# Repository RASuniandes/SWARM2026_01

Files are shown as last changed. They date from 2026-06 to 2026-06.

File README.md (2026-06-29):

# SWARM - Sistema de Control para Robot Móvil

## Descripción General

Este repositorio contiene el sistema completo de control para un robot móvil de 4 ruedas omnidireccionales, desarrollado en la Universidad de los Andes. El proyecto integra:

- **Hardware**: ESP32 con 4 motores DC con encoders y drivers L8871
- **Software**: ROS 2 (Robot Operating System) con múltiples modos de control
- **Sensores**: LiDAR YDLidar para navegación autónoma
- **Visión**: MediaPipe para seguimiento de personas

## Estructura del Proyecto

```
SWARM/
├── ros4meetup/              # Paquete principal ROS2
│   ├── ros4meetup/          # Workspace de ROS2
│   │   ├── src/             # Código fuente
│   │   │   ├── ros4meetup/  # Nodos de control
│   │   │   ├── lidar/       # Driver del LiDAR
│   │   │   └── ...          # Otros paquetes
│   │   └── ...              # Build, install, log
│   └── README.md            # Documentación detallada de ROS2
├── CódigoControl/           # Firmware para ESP32 (Arduino)
├── Control SWARM/           # Diseños de PCB (KiCad)
├── Electrónica/             # Esquemáticos y documentación electrónica
├── Dashboard preliminar/    # Interfaz web de monitoreo
└── ojos_frontales/          # Codigo ESP32 para ojos (Matriz 64x2)
```

## Características Principales

### Modos de Control

1. **Vision** (por defecto): Seguimiento de personas usando MediaPipe
2. **Autonomous**: Navegación autónoma con evitación de obstáculos (LiDAR)
3. **Teleop**: Control manual por teclado (W/A/S/D)
4. **Remote**: Control remoto desde ESP32
5. **Web**: Control desde interfaz web

### Arquitectura

```
[Controladores]  →  [Router]  →  [Serial Bridge]  →  [ESP32]  →  [Motores]
                      ↓ cmd_vel
                  [Comandos de velocidad]
```

Cada controlador publica en su propio topic (`vision_command`, `autonomous_command`, etc.). El **Router** selecciona qué controlador está activo y reenvía sus comandos a `cmd_vel`. El **Serial Bridge** convierte estos comandos a JSON y los envía al ESP32 por puerto serial.

## Inicio Rápido

### Requisitos

- Ubuntu 22.04 o superior
- ROS 2 Humble
- Python 3.10+
- Arduino IDE (para firmware ESP32)

### Instalación

1. **Clonar el repositorio:**
```bash
git clone https://github.com/RASuniandes/SWARM.git
cd SWARM/ros4meetup
```

2. **Configurar el entorno ROS2:**
```bash
source ros4meetup/ros.bash
```

3. **Compilar el workspace:**
```bash
cd ros4meetup
colcon build
source install/setup.bash
```

4. **Cargar firmware en ESP32:**
   - Ver documentación en `ros4meetup/firmware/README.md`

### Ejecución

1. **Iniciar el sistema básico:**
```bash
# Terminal 1: Router
ros2 run ros4meetup router

# Terminal 2: Serial Bridge
ros2 run ros4meetup serial_bridge

# Terminal 3: Controlador (elige uno)
ros2 run ros4meetup vision_controller
# o
ros2 run ros4meetup autonomous_controller
# o
ros2 run ros4meetup teleop_controller
```

2. **Cambiar de modo:**
```bash
ros2 topic pub /config std_msgs/String "data: 'autonomous'" --once
```

## Documentación Adicional

- **ROS2 y Nodos**: Ver `ros4meetup/README.md`
- **Firmware ESP32**: Ver `ros4meetup/firmware/README.md`
- **Electrónica**: Ver `Electrónica/`
- **PCB**: Ver `Control SWARM/`

## Desarrollo

### Estructura de Topics ROS2

- `/cmd_vel` (Twist): Comandos de velocidad final al robot
- `/config` (String): Cambio de modo de control
- `/vision_command` (Twist): Comandos del controlador de visión
- `/autonomous_command` (Twist): Comandos del controlador autónomo
- `/teleop_command` (Twist): Comandos del control por teclado
- `/remote_command` (Twist): Comandos remotos desde ESP32
- `/laser_scan` (LaserScan): Datos del LiDAR
- `/esp_feedback` (String): Retroalimentación del ESP32
- `/faces_direction` (String): Dirección para LEDs faciales

### Hardware

- **Microcontrolador**: ESP32
- **Motores**: 4x DC con reductora 1:80 y encoders (12 PPR)
- **Drivers**: L8871 (H-bridge)
- **Sensor**: YDLidar X4
- **Cámara**: USB o CSI para visión

## Licencia

MIT

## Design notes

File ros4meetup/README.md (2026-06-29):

# ros4meetup - Paquete ROS2 para Control de Robot SWARM

## Índice

1. [Descripción General](#descripción-general)
2. [Arquitectura del Sistema](#arquitectura-del-sistema)
3. [Nodos y Funcionalidad](#nodos-y-funcionalidad)
4. [Instalación](#instalación)
5. [Uso](#uso)
6. [Topics y Mensajes](#topics-y-mensajes)
7. [Dependencias](#dependencias)
8. [Solución de Problemas](#solución-de-problemas)

---

## Descripción General

`ros4meetup` es un paquete ROS2 Humble que implementa un sistema de control multi-modal para un robot móvil con 4 ruedas omnidireccionales. El sistema permite cambiar entre diferentes estrategias de control de manera dinámica:

- 👁️ **Visión por computadora**: Seguimiento de personas con MediaPipe
- 🤖 **Navegación autónoma**: Evitación de obstáculos con LiDAR
- 🎮 **Control manual**: Teclado (WASD)
- 📱 **Control remoto**: Desde ESP32 o aplicación móvil
- 🌐 **Interfaz web**: Dashboard de monitoreo y control

### Características

- **Arquitectura modular**: Cada modo de control es un nodo independiente
- **Cambio de modo en caliente**: Sin necesidad de reiniciar el sistema
- **Comunicación serial robusta**: Bridge bidireccional con ESP32
- **Integración con sensores**: LiDAR YDLidar X4 y cámara USB/CSI

---

## Arquitectura del Sistema

```
┌───────────────────────────────────────────────┐
│              CONTROLADORES ROS2               │
│  ┌────────────────────────────────────────┐   │
│  │  vision_controller                     │   │
│  │  autonomous_controller                 │   │
│  │  teleop_controller                     │   │
│  │  (web_controller)                      │   │
│  └─────────────────┬──────────────────────┘   │
│                    │                          │
│                    │ *_command topics         │
│                    │                          │
│                    ↓                          │
│           ┌───────────────────┐               │
│           │   ROUTER          │               │
│           │  (Selector de     │               │
│           │   modo activo)    │               │
│           └────────┬─────────-┘               │
│                    │                          │
│                    │ /cmd_vel                 │
│                    ↓                          │
│           ┌───────────────────┐               │
│           │  SERIAL BRIDGE    │               │
│           │  (ROS ↔ JSON)     │               │
│           └────────┬──────────┘               │
└────────────────────│──────────────────────────┘
                     │ Serial USB (/dev/ttyUSB0)
                     ↓
            ┌────────────────────┐
            │      ESP32         │
            │  (Control de       │
            │   motores)         │
            └────────┬───────────┘
                     │
                     ↓
          ┌────────────────────────┐
          │  4 Motores + Encoders  │
          └────────────────────────┘
```

### Flujo de Datos

1. **Generación de Comandos**: Los controladores leen sensores (cámara, LiDAR, teclado) y publican comandos `Twist` en sus topics específicos
2. **Selección**: El Router suscribe al topic del modo activo y reenvía a `/cmd_vel`
3. **Serialización**: Serial Bridge convierte `Twist` a JSON: `{"linear_speed": X, "angular_speed": Z}`
4. **Transmisión**: Envía el JSON por serial a ESP32
5. **Control de Hardware**: ESP32 calcula PWM para cada motor y cierra el lazo con encoders

---

## Nodos y Funcionalidad

### 1. `router` - Enrutador de Modos

**Archivo**: `src/ros4meetup/router.py`

**Función**: Selecciona dinámicamente qué controlador tiene prioridad.

**Topics**:
- **Suscribe**: `/config` (String) - Cambio de modo
- **Suscribe**: `/{mode}_command` (Twist) - Comandos del modo activo
- **Publica**: `/cmd_vel` (Twist) - Comandos seleccionados

**Modos válidos**: `remote`, `autonomous`, `vision`, `web`, `teleop`

**Ejemplo de uso**:
```bash
# Cambiar a modo autónomo
ros2 topic pub /config std_msgs/String "data: 'autonomous'" --once
```

---

### 2. `serial_bridge` - Puente Serial

**Archivo**: `src/ros4meetup/serial_bridge.py`

**Función**: Traduce mensajes ROS2 ↔ JSON para comunicación con ESP32.

**Características**:
- **Comunicación bidireccional**: Lee y escribe en puerto serial
- **Thread separado** para lectura no bloqueante
- **Puerto**: `/dev/ttyUSB0` a 115200 baudios

**Topics**:
- **Suscribe**: `/cmd_vel` (Twist)
- **Publica**: `/esp_feedback` (String) - Mensajes del ESP32
- **Publica**: `/remote_command` (Twist) - Control remoto desde ESP32

**Formato JSON enviado al ESP32**:
```json
{
  "linear_speed": 100,
  "angular_speed": 50
}
```

**Formato JSON recibido del ESP32**:
```json
{
  "mode": "autonomous",
  "feedback": "Battery: 12.5V",
  "remote_control": {"x": 50, "z": -20}
}
```

---

### 3. `vision_controller` - Seguimiento de Personas

**Archivo**: `src/ros4meetup/vision_controller.py`

**Función**: Sigue a una persona usando detección de pose con MediaPipe.

**Algoritmo**:
1. **Detección**: Identifica hombros o caderas de la persona más cercana
2. **Centrado lateral**: Calcula velocidad angular para centrar la persona
3. **Distancia**: Estima profundidad por tamaño (ratio de ancho de hombros)
4. **Control**:
   - Si está muy cerca (ratio > 0.4): retrocede
   - Si está bien (0.25-0.4): se detiene
   - Si está lejos (< 0.25): avanza

**Topics**:
- **Publica**: `/vision_command` (Twist)

**Parámetros**:
- Velocidad máxima: 100 (normalizada)
- FPS: 10 Hz

---

### 4. `autonomous_controller` - Navegación Autónoma

**Archivo**: `src/ros4meetup/autonomous_controller.py`

**Función**: Navega evitando obstáculos usando datos del LiDAR.

**Algoritmo**:
1. **Lectura**: Procesa datos del LiDAR en 3 zonas (frente, izquierda, derecha)
2. **Detección de obstáculos**: Si la distancia frontal < 0.5m
3. **Decisión**: Gira hacia el lado con más espacio
4. **Ejecución**: Avanza o gira según la situación

**Topics**:
- **Suscribe**: `/laser_scan` (LaserScan)
- **Publica**: `/autonomous_command` (Twist)

**Parámetros**:
- Velocidad lineal: 70
- Velocidad angular: 70
- Distancia mínima: 0.5 metros

---

### 5. `teleop_controller` - Control Manual

**Archivo**: `src/ros4meetup/teleop_controller.py`

**Función**: Control por teclado en tiempo real.

**Teclas**:
- `W`: Avanzar
- `S`: Retroceder
- `A`: Girar izquierda
- `D`: Girar derecha
- `SPACE`: Detener
- `Q`: Salir

**Topics**:
- **Publica**: `/teleop_command` (Twist)

---

### 6. `ojosnodo` - Control de LEDs Faciales

**Archivo**: `src/ros4meetup/ojosnodo.py`

**Función**: Detecta la dirección de movimiento y publica comandos para LEDs "faciales" del robot.

**Lógica**:
- Analiza `/cmd_vel` y determina dirección: `front`, `back`, `left`, `right`, `none`
- Publica en `/faces_direction` para que el ESP32 encienda los LEDs correspondientes

**Topics**:
- **Suscribe**: `/cmd_vel` (Twist)
- **Publica**: `/faces_direction` (String)

---

## Instalación

### Prerrequisitos

```bash
# ROS2 Humble (Ubuntu 22.04)
sudo apt update
sudo apt install ros-humble-desktop python3-colcon-common-extensions

# Dependencias Python
sudo apt install python3-pip
pip3 install pyserial mediapipe opencv-python

# Driver del LiDAR YDLidar
sudo apt install ros-humble-ydlidar-ros2-driver
```

### Compilación

```bash
cd ~/Documents/Ivan/Uniandes/SWARM/ros4meetup/ros4meetup

# Compilar todos los paquetes
colcon build

# Compilar solo ros4meetup
colcon build --packages-select ros4meetup

# Source del workspace
source install/setup.bash
# o, hacer ros.bash, asegurando que sea ejectuable
chmod -x ./ros.bah
./ros.bash
```

### Configuración del Puerto Serial

```bash
# Dar permisos al usuario para acceder a puertos seriales
sudo usermod -aG dialout $USER
# Cerrar sesión y volver a entrar

# Verificar que el ESP32 esté conectado
ls /dev/ttyUSB*
# Debería mostrar: /dev/ttyUSB0 (o similar)

# Si es necesario, modificar el puerto en serial_bridge.py línea 22
```

---

## Uso

### Inicio Completo del Sistema

**Opción 1: Terminales Separadas**

```bash
# Terminal 1: Router
source ~/SWARM/ros4meetup/ros4meetup/install/setup.bash
ros2 run ros4meetup router

# Terminal 2: Serial Bridge
source ~/SWARM/ros4meetup/ros4meetup/install/setup.bash
ros2 run ros4meetup serial_bridge

# Terminal 3: Controlador de Visión (modo por defecto)
source ~/SWARM/ros4meetup/ros4meetup/install/setup.bash
ros2 run ros4meetup vision_controller

# Terminal 4 (opcional): Nodo de LEDs faciales
source ~/SWARM/ros4meetup/ros4meetup/install/setup.bash
ros2 run ros4meetup ojosnodo
```

**Opción 2: Usando tmux o screen**

```bash
# Crear script de inicio
cat > ~/start_swarm.sh << 'EOF'
#!/bin/bash
source ~/SWARM/ros4meetup/ros4meetup/install/setup.bash

tmux new-session -d -s swarm
tmux send-keys -t swarm 'ros2 run ros4meetup router' C-m
tmux split-window -t swarm
tmux send-keys -t swarm 'ros2 run ros4meetup serial_bridge' C-m
tmux split-window -t swarm
tmux send-keys -t swarm 'ros2 run ros4meetup vision_controller' C-m
tmux attach -t swarm
EOF

chmod +x ~/start_swarm.sh
./start_swarm.sh
```

### Cambio de Modo de Control

```bash
# Cambiar a modo autónomo (requiere LiDAR)
ros2 topic pub /config std_msgs/String "data: 'autonomous'" --once
ros2 run ros4meetup autonomous_controller

# Cambiar a control por teclado
ros2 topic pub /config std_msgs/String "data: 'teleop'" --once
ros2 run ros4meetup teleop_controller

# Volver a modo de visión
ros2 topic pub /config std_msgs/String "data: 'vision'" --once
```

### Monitoreo

```bash
# Ver lista de nodos activos
ros2 node list

# Ver topics activos
ros2 topic list

# Monitorear comandos de velocidad
ros2 topic echo /cmd_vel

# Ver información del LiDAR
ros2 topic echo /laser_scan

# Ver feedback del ESP32
ros2 topic echo /esp_feedback

# Visualizar en RViz
ros2 run rviz2 rviz2
# Agregar: LaserScan (/laser_scan), TF, etc.
```

---

## Topics y Mensajes

### Topics Principales

| Topic | Tipo | Dirección | Descripción |
|---|---|---|---|
| `/cmd_vel` | Twist | ROS → ESP | Comandos de velocidad finales |
| `/config` | String | Usuario | Selección de modo de control |
| `/vision_command` | Twist | Nodo | Comandos del controlador de visión |
| `/autonomous_command`| Twist | Nodo | Comandos del controlador autónomo |
| `/teleop_command` | Twist | Nodo | Comandos del control por teclado |
| `/remote_command` | Twist | ESP → ROS | Comandos remotos desde ESP32 |
| `/laser_scan` | LaserScan | LiDAR | Datos del sensor LiDAR |
| `/esp_feedback` | String | ESP → ROS | Retroalimentación del microcontrolador |
| `/faces_direction` | String | ROS → ESP | Dirección para LEDs faciales |

### Estructura del Mensaje Twist

```python
geometry_msgs/Twist:
  linear:
    x: float  # Velocidad lineal (0-100 para este robot)
    y: 0.0    # No usado (robot no holonómico)
    z: 0.0    # No usado
  angular:
    x: 0.0    # No usado
    y: 0.0    # No usado
    z: float  # Velocidad angular (0-100 para este robot)
```

---

## Dependencias

### Paquetes ROS2

```xml
<depend>rclpy</depend>
<depend>std_msgs</depend>
<depend>geometry_msgs</depend>
<depend>sensor_msgs</depend>
<depend>std_srvs</depend>
```

### Bibliotecas Python

```bash
pip3 install pyserial      # Comunicación serial
pip3 install mediapipe     # Detección de pose
pip3 install opencv-python # Procesamiento de imagen
```

### Hardware

- **ESP32**: Microcontrolador principal
- **4 Motores DC**: Con reductora 1:80 y encoders de 12 PPR
- **Drivers L8871**: H-bridge para control de motores
- **YDLidar X4**: Sensor LiDAR de 360°
- **Cámara USB o CSI**: Para visión por computadora

---

## Solución de Problemas

### Error: "Could not open serial port"

```bash
# Verificar permisos
ls -l /dev/ttyUSB0
sudo chmod 666 /dev/ttyUSB0

# Agregar usuario al grupo dialout
sudo usermod -aG dialout $USER
# Cerrar sesión y volver a entrar
```

### Error: "Could not open camera"

```bash
# Verificar dispositivos de cámara
ls /dev/video*

# Probar cámara con OpenCV
python3 -c "import cv2; cap = cv2.VideoCapture(0); print(cap.isOpened())"

# Si no funciona, cambiar índice en vision_controller.py línea 16
# cv2.VideoCapture(1)  # o 2, 3, etc.
```

### Error: "Config service not available"

```bash
# Verificar que el router esté corriendo
ros2 node list | grep router

# Reiniciar el router
ros2 run ros4meetup router
```

### El robot no se mueve

```bash
# 1. Verificar que el ESP32 esté recibiendo datos
ros2 topic echo /cmd_vel

# 2. Verificar serial bridge
ros2 topic echo /esp_feedback

# 3. Revisar logs del serial_bridge
# Debería mostrar: "Sending to ESP32: linear=X, angular=Z"

# 4. Verificar modo activo
ros2 topic pub /config std_msgs/String "data: 'vision'" --once
```

### Bajo rendimiento en visión

```bash
# Reducir resolución de cámara
# En vision_controller.py, después de la línea 16:
# self.cap.set(cv2.CAP_PROP_FRAME_WIDTH, 640)
# self.cap.set(cv2.CAP_PROP_FRAME_HEIGHT, 480)

# Reducir complejidad del modelo MediaPipe
# En vision_controller.py línea 25:
# model_complexity=0  # en lugar de 1
```

### LiDAR no detecta obstáculos

```bash
# Verificar datos del LiDAR
ros2 topic echo /laser_scan --once

# Visualizar en RViz
ros2 run rviz2 rviz2
# Add > LaserScan > Topic: /laser_scan

# Ajustar distancia mínima en autonomous_controller.py línea 22
# self.min_distance = 0.3  # o valor deseado
```

---

## Estructura de Archivos

```
ros4meetup/
├── ros4meetup/                  # Workspace ROS2
│   ├── src/
│   │   ├── ros4meetup/          # Paquete principal
│   │   │   ├── router.py        # Enrutador de modos
│   │   │   ├── serial_bridge.py # Puente serial ROS-ESP32
│   │   │   ├── vision_controller.py
│   │   │   ├── autonomous_controller.py
│   │   │   ├── teleop_controller.py
│   │   │   ├── ojosnodo.py
│   │   │   └── __init__.py
│   │   ├── setup.py             # Configuración del paquete
│   │   ├── package.xml          # Metadatos y dependencias
│   │   ├── lidar/               # Driver del LiDAR
│   │   └── ...                  # Otros paquetes
│   ├── build/                   # Archivos de compilación
│   ├── install/                 # Instalación del workspace
│   └── log/                     # Logs de compilación
├── firmware/                    # Firmware del ESP32
│   ├── br_motoresesp_RAS.ino   # Código Arduino
│   └── README.md               # Documentación del firmware
└── README.md                    # Este archivo
```

---

## Desarrollo y Extensión

### Añadir un Nuevo Modo de Control

1. **Crear el nodo** en `src/ros4meetup/mi_controlador.py`:

```python
import rclpy
from rclpy.node import Node
from geometry_msgs.msg import Twist

class MiControlador(Node):
    def __init__(self):
        super().__init__('mi_controlador')
        self.publisher_ = self.create_publisher(Twist, 'mi_modo_command', 10)
        self.timer = self.create_timer(0.1, self.timer_callback)
    
    def timer_callback(self):
        twist = Twist()
        # ... tu lógica aquí ...
        self.publisher_.publish(twist)

def main(args=None):
    rclpy.init(args=args)
    node = MiControlador()
    rclpy.spin(node)
    node.destroy_node()
    rclpy.shutdown()
```

2. **Registrar en setup.py**:

```python
entry_points={
    'console_scripts': [
        # ... otros entry points ...
        'mi_controlador = ros4meetup.mi_controlador:main',
    ],
},
```

3. **Añadir al router** en `router.py` línea 12:

```python
self.valid_modes = ['remote', 'autonomous', 'vision', 'web', 'teleop', 'mi_modo']
```

4. **Compilar y ejecutar**:

```bash
colcon build --packages-select ros4meetup
source install/setup.bash
ros2 run ros4meetup mi_controlador
ros2 topic pub /config std_msgs/String "data: 'mi_modo'" --once
```

### Modificar el Protocolo Serial

Si necesitas enviar datos adicionales al ESP32:

1. **En serial_bridge.py**, modificar `cmd_vel_callback` (línea 59):

```python
data = {
    'angular_speed': int(msg.angular.z),
    'linear_speed': int(msg.linear.x),
    'timestamp': time.time(),  # Nuevo campo
    'mode': self.current_mode  # Nuevo campo
}
```

2. **En el firmware ESP32**, actualizar el parsing JSON

---

## Recursos Adicionales

- **ROS2 Humble Docs**: https://docs.ros.org/en/humble/
- **MediaPipe Pose**: https://google.github.io/mediapipe/solutions/pose
- **YDLidar ROS2**: https://github.com/YDLIDAR/ydlidar_ros2_driver
- **ESP32 Arduino Core**: https://github.com/espressif/arduino-esp32

---

## Licencia

MIT License

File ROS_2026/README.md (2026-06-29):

# SWARM 2026-2 Software Documentation

## 1. Overall System Architecture
The software implementation is designed to be modular and scalable. It utilizes a web-based interface integrated with AWS Lambda/Firebase functions for fleet management. The robots maintain local autonomy, receiving high-level instructions from the cloud.

### Communication Flow
* **Cloud-to-Robot:** Instructions sent via secure socket/API to the robot’s custom bridge.
* **Map Management:** Maps are sent periodically or on-demand from the robot to the cloud to optimize bandwidth and cloud storage costs.

---

## 2. Node Specifications

### A. Operational Nodes (Lifecycle Enabled)
These nodes output velocity commands to the `Router`.

| Node | Topic (Output) | Primary Parameters |
| :--- | :--- | :--- |
| **Teleop Node** | `/cmd_teleop` | `linear_speed`, `angular_speed` |
| **Hand Node** | `/cmd_hand` | `sensitivity`, `gesture_map` |
| **Vision Node** | `/cmd_vision` | `sensitivity`, `cue_map` |
| **Autonomous Node** | `/cmd_nav` | `max_vel`, `max_accel`, `mission_map` |
(Will be a router_listener topic for the router to send the nodes which node he is listening to: `/router_listener`)
### B. Core Controller Nodes
| Node | Name/Type | Purpose/Interface |
| :--- | :--- | :--- |
| **Router** | `router_node` | Arbitration node. **Param:** `current_mode`. **Action:** `switch_mode`. |
| **Serial Bridge** | `bridge_node` | **Topic (Sub):** `/cmd_vel` (final), `/lift_cmd`. **Interface:** Serial to ESP. |
| **Lift Controller**| `lift_node` | **Action:** `move_lift`. **Params:** `max_height`, `speed`, `limit_safety`. |

### C. Perception & Infrastructure Nodes
| Node | Topic (Output) | Purpose |
| :--- | :--- | :--- |
| **Odom Listener** | `/odom` | Publishes encoder/IMU feedback from ESP. |
| **Lidar Listener** | `/scan` | Raw data ingestion to ROS 2. |
| **SLAM Toolbox** | `/map`, `/map_metadata` | Simultaneous Localization and Mapping. |

### D. Monitoring Nodes
| Node | Topic (Output) | Responsibility |
| :--- | :--- | :--- |
| **Health Monitor** | `/status/hardware` | Battery, sensor status, actuator errors. |
| **Node Health** | `/status/nodes` | Heartbeat, resource usage (CPU/RAM), availability. |

---

## 3. Communication Interface Details

### Custom WebSocket/API Bridge
Since standard `rosbridge` is omitted for security, this custom node performs:
1. **Serialization:** Implementation of Protobuf for binary message efficiency.
2. **Security:** mTLS handshake between the AWS/Firebase endpoint and the local bridge node.
3. **Map Throttling:** Logic to transmit map updates only when the `map_change_threshold` is exceeded to keep the bill low.

### ESP-to-Robot PWM Logic
The ESP32 acts as an isolated hardware controller:
* **Input:** Receives structured serial packets from `Serial Bridge`.
* **Output:** Local PWM generation for motors and lift actuators.
* **Safety:** If serial connection heartbeat is lost (Timeout: 50ms), the ESP enters a "Safe Halt" state independently of the ROS 2 network.

---

## 4. Configuration & Lifecycle Management (`launch.py`)

The `launch.py` file serves as the centralized orchestrator.

* **Lifecycle Sequence:**
    1.  **Hardware Drivers:** `Serial Bridge`, `Lidar Listener`.
    2.  **Navigation/Mapping:** `SLAM Toolbox`, `Map Server`.
    3.  **Core Logic:** `Router`, `Mission Controller`.
    4.  **Operational Nodes:** `Teleop`, `Vision`, etc.
* **Orchestration:** Each node is defined as a `LifecycleNode`. The launch file monitors the transition from `Unconfigured` -> `Inactive` -> `Active`.
* **Visualization:** Includes standard configuration for `rviz2` to visualize `/map`, `/odom`, and `/cmd_vel` paths.

---

## 5. Implementation Logic Checklist
* [ ] **Router Arbitration:** Ensure "Autonomous" mode is preempted if "Teleop" node sends a command.
* [ ] **Map Management:** Implement a service call `update_map` that triggers only when the robot's exploration status changes significantly.
* [ ] **Lifecycle States:** Ensure all nodes are configured to handle `on_shutdown` gracefully to prevent hardware from locking in a powered state.

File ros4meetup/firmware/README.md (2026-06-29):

# Firmware ESP32 - Control de Motores para Robot SWARM

## Descripción General

Este firmware está diseñado para ejecutarse en un **ESP32** y controlar 4 motores DC con encoders mediante drivers L8871 (H-bridge). El código implementa:

- **Comunicación serial bidireccional** (JSON) con ROS2
- **Control PWM** de 4 motores independientes
- **Lectura de encoders** mediante interrupciones
- **Cálculo de RPM en tiempo real**
- **Clase modular** para manejo de motores

---

## Índice

1. [Hardware](#hardware)
2. [Configuración de Pines](#configuración-de-pines)
3. [Arquitectura del Código](#arquitectura-del-código)
4. [Protocolo de Comunicación](#protocolo-de-comunicación)
5. [Instalación](#instalación)
6. [Uso](#uso)
7. [Explicación Detallada del Código](#explicación-detallada-del-código)
8. [Solución de Problemas](#solución-de-problemas)

---

## Hardware

### Componentes Principales

- **Microcontrolador**: ESP32 DevKit v1 (o compatible)
- **Motores**: 4x motores DC con reductora 1:80
- **Encoders**: Encoders cuadráticos de 12 PPR (pulsos por revolución)
- **Drivers**: 4x L8871 (H-bridge, control bidireccional)
- **Alimentación**: 
  - ESP32: 5V via USB o regulador
  - Motores: 12V (batería o fuente externa)

### Especificaciones de los Motores

- **Voltaje nominal**: 12V DC
- **Relación de reducción**: 1:80
- **Encoders**: 12 PPR en el eje del motor
- **PPR efectivo después de reductora**: 12 × 80 = 960 PPR en el eje de salida

---

## Configuración de Pines

### Tabla de Conexiones

| Motor | IN1 (PWM) | IN2 (PWM) | Canal PWM 1 | Canal PWM 2 | Encoder A | Encoder B |
|---|---|---|---|---|---|---|
| **Motor 1** | GPIO 1  | GPIO 2  | CH0 | CH1 | GPIO 4  | GPIO 5  |
| **Motor 2** | GPIO 6  | GPIO 7  | CH2 | CH3 | GPIO 17 | GPIO 18 |
| **Motor 3** | GPIO 8  | GPIO 3  | CH4 | CH5 | GPIO 9  | GPIO 10 |
| **Motor 4** | GPIO 11 | GPIO 12 | CH6 | CH7 | GPIO 13 | GPIO 14 |

### Pines I2C (No usados actualmente)

- **SDA**: GPIO 15
- **SCL**: GPIO 16

*Nota: Estos pines están definidos pero no se usan en esta versión del código*

---

## Arquitectura del Código

### Estructura General

```
┌─────────────────────────────────────────┐
│         setup() - Inicialización       │
│  - Serial 115200 baudios               │
│  - Inicialización de 4 motores         │
│  - Configuración de interrupciones     │
└─────────────┬───────────────────────────┘
              │
              ↓
┌─────────────────────────────────────────┐
│          loop() - Ciclo principal       │
│  ┌───────────────────────────────────┐  │
│  │ 1. Leer JSON desde serial        │  │
│  │    {"linear_speed": X,           │  │
│  │     "angular_speed": Z}          │  │
│  └───────────────────────────────────┘  │
│  ┌───────────────────────────────────┐  │
│  │ 2. Actualizar RPM de encoders    │  │
│  │    (cada 500ms)                  │  │
│  └───────────────────────────────────┘  │
│  ┌───────────────────────────────────┐  │
│  │ 3. Controlar motores             │  │
│  │    (forward/backward/stop)       │  │
│  └───────────────────────────────────┘  │
│  ┌───────────────────────────────────┐  │
│  │ 4. Publicar RPM por serial       │  │
│  │    (cada 1000ms)                 │  │
│  └───────────────────────────────────┘  │
└─────────────────────────────────────────┘
```

### Clase `Motor`

Cada motor se encapsula en una clase que gestiona:

- **Control PWM**: Avanzar, retroceder, detener
- **Lectura de encoders**: Mediante interrupciones (ISR)
- **Cálculo de RPM**: Basado en pulsos contados
- **Estado interno**: Pulsos acumulados, última lectura, tiempo

---

## Protocolo de Comunicación

### Formato de Mensajes

La comunicación con ROS2 (vía `serial_bridge`) usa **JSON** con terminador de línea `\n`.

#### 1. Comandos ROS2 → ESP32

```json
{
  "linear_speed": 100,
  "angular_speed": 50
}
```

**Campos**:
- `linear_speed` (int): Velocidad lineal del robot (-100 a 100)
  - Positivo: avanzar
  - Negativo: retroceder
  - 0: detenido
- `angular_speed` (int): Velocidad de rotación (-100 a 100)
  - Positivo: girar a la derecha
  - Negativo: girar a la izquierda
  - 0: sin rotación

#### 2. Retroalimentación ESP32 → ROS2

```json
{
  "rpm1": 45.2,
  "rpm2": 44.8,
  "rpm3": 45.5,
  "rpm4": 44.9,
  "battery": 12.3,
  "mode": "autonomous"
}
```

**Campos opcionales**:
- `rpm1`, `rpm2`, `rpm3`, `rpm4`: RPM de cada motor
- `battery`: Voltaje de batería (si se implementa)
- `mode`: Solicitud de cambio de modo
- `feedback`: Mensajes de estado
- `remote_control`: Comandos desde control remoto

---

## Instalación

### Requisitos

1. **Arduino IDE** (versión 2.x recomendada) o **PlatformIO**
2. **Soporte para ESP32**:
   - En Arduino IDE: 
     - `Archivo → Preferencias → URLs adicionales de gestor de tarjetas`
     - Agregar: `https://raw.githubusercontent.com/espressif/arduino-esp32/gh-pages/package_esp32_index.json`
     - `Herramientas → Placa → Gestor de tarjetas → ESP32 → Instalar`

3. **Biblioteca ArduinoJson**:
   - `Herramientas → Administrar bibliotecas`
   - Buscar "ArduinoJson" por Benoit Blanchon
   - Instalar versión 6.x

### Pasos de Instalación

```bash
# 1. Clonar el repositorio (si aún no lo has hecho)
git clone https://github.com/RASUniandes/SWARM

# 2. Abrir el firmware
# En Arduino IDE: Archivo → Abrir → ros4meetup/firmware/br_motoresesp_RAS.ino
```

### Configuración en Arduino IDE

1. **Seleccionar placa**: `Herramientas → Placa → ESP32 Arduino → ESP32 Dev Module`
2. **Puerto**: `Herramientas → Puerto → /dev/ttyUSB0` (Linux) o `COM#` (Windows)
3. **Configuración avanzada**:
   - Upload Speed: 921600
   - Flash Frequency: 80MHz
   - Flash Mode: QIO
   - Partition Scheme: Default 4MB with spiffs

### Cargar el Firmware

1. **Verificar**: `Sketch → Verificar/Compilar` (Ctrl+R)
2. **Cargar**: `Sketch → Subir` (Ctrl+U)
3. **Monitor Serial**: `Herramientas → Monitor Serie` (115200 baudios)

---

## Uso

### Prueba Básica sin ROS2

```bash
# Abrir monitor serial (115200 baudios)
# Enviar comandos JSON manualmente:

{"linear_speed": 100, "angular_speed": 0}   # Avanzar
{"linear_speed": -50, "angular_speed": 0}   # Retroceder
{"linear_speed": 0, "angular_speed": 100}   # Girar derecha
{"linear_speed": 0, "angular_speed": 0}     # Detener
```

### Integración con ROS2

Una vez cargado el firmware, el ESP32 se comunica automáticamente con el nodo `serial_bridge` de ROS2.

```bash
# En tu sistema ROS2
ros2 run ros4meetup serial_bridge

# En otra terminal, enviar comandos
ros2 topic pub /cmd_vel geometry_msgs/Twist \
  "{linear: {x: 50.0}, angular: {z: 0.0}}" --once
```

### Monitoreo de RPM

```bash
# Ver feedback del ESP32 en ROS2
ros2 topic echo /esp_feedback
```

---

## Explicación Detallada del Código

### Sección 1: Definición de Pines (Líneas 43-66)

```cpp
#define M1_IN1 1
#define M1_IN2 2
#define ENC1_A 4
#define ENC1_B 5
// ... (similar para M2, M3, M4)
```

**¿Qué hace?**
- Define los pines GPIO del ESP32 para cada motor y encoder
- `M#_IN1/IN2`: Pines de control del H-bridge (dirección + velocidad)
- `ENC#_A/B`: Señales cuadráticas del encoder (fase A y B)

---

### Sección 2: Clase Motor (Líneas 69-173)

#### Constructor (Líneas 83-95)

```cpp
Motor(int _in1, int _in2, int _ch1, int _ch2, int _encA, int _encB)
```

**Parámetros**:
- `_in1`, `_in2`: Pines GPIO de control
- `_ch1`, `_ch2`: Canales PWM del ESP32 (0-15 disponibles)
- `_encA`, `_encB`: Pines GPIO del encoder

**Inicializa**:
- Contadores de pulsos a 0
- Configuración de tiempo para cálculo de RPM

---

#### Método `init()` (Líneas 97-110)

**Funciones**:

1. **Configuración de PWM**:
```cpp
ledcSetup(ch1, 1000, 8);  // Canal, Frecuencia (1kHz), Resolución (8 bits)
ledcAttachPin(in1, ch1);   // Asociar GPIO al canal PWM
```
- Frecuencia: 1000 Hz (período de 1ms)
- Resolución: 8 bits → valores de 0 a 255

2. **Configuración de encoders**:
```cpp
pinMode(encA, INPUT_PULLUP);  // Resistencia pull-up interna
attachInterruptArg(digitalPinToInterrupt(encA), isrA, this, CHANGE);
```
- `INPUT_PULLUP`: Activa resistencia pull-up (señal estable)
- `attachInterruptArg`: Asocia ISR al cambio de estado del pin
- `this`: Pasa el objeto Motor a la ISR

---

#### Métodos de Control (Líneas 112-128)

**1. `forward(int speed)`**: Avanzar
```cpp
ledcWrite(ch1, speed);  // IN1 = PWM
ledcWrite(ch2, 0);      // IN2 = 0
```
- Corriente fluye de IN1 a IN2 → motor gira en un sentido

**2. `backward(int speed)`**: Retroceder
```cpp
ledcWrite(ch1, 0);      // IN1 = 0
ledcWrite(ch2, speed);  // IN2 = PWM
```
- Corriente fluye de IN2 a IN1 → motor gira en sentido opuesto

**3. `stop()`**: Detener
```cpp
ledcWrite(ch1, 0);
ledcWrite(ch2, 0);
```
- Sin corriente → freno eléctrico

---

#### Cálculo de RPM (Líneas 130-141)

```cpp
void updateRPM() {
    unsigned long now = millis();
    if (now - lastTime >= 500) {  // Cada 500ms
        long delta = pulsos - lastPulsos;  // Pulsos nuevos
        float tiempoSeg = (now - lastTime) / 1000.0;
        
        rpm = (delta / (float)pulsosPorVuelta) * (60.0 / tiempoSeg) / reduccion;
        //     └─────────────────────┬────────────────────┘   └──┬───┘
        //                      Vueltas/seg                 Ajuste reductora
        
        lastPulsos = pulsos;
        lastTime = now;
    }
}
```

**Fórmula explicada**:

1. **Pulsos a vueltas**: `delta / pulsosPorVuelta`
   - Ejemplo: 24 pulsos / 12 PPR = 2 vueltas del motor

2. **Vueltas por segundo**: `vueltas / tiempoSeg`
   - Ejemplo: 2 vueltas / 0.5 seg = 4 vueltas/seg

3. **RPM**: `vueltas/seg × 60`
   - Ejemplo: 4 vueltas/seg × 60 = 240 RPM (motor)

4. **RPM del eje de salida**: `RPM_motor / reduccion`
   - Ejemplo: 240 RPM / 80 = 3 RPM (eje final)

---

#### Encoders e Interrupciones (Líneas 153-172)

```cpp
void encoderChange(bool a, bool b) {
    if (a == b)
        pulsos++;  // Giro horario
    else
        pulsos--;  // Giro antihorario
}
```

**Principio del encoder cuadrático**:

```
Giro horario (→):
  A: ──┐   ┌───┐   ┌──
      └───┘   └───┘
  B: ────┐   ┌───┐   ┌
         └───┘   └───┘
         ↑ A==B → incrementar

Giro antihorario (←):
  A: ──┐   ┌───┐   ┌──
      └───┘   └───┘
  B: ┌───┐   ┌───┐
     └───┘   └───┘
     ↑ A≠B → decrementar
```

**ISR (Interrupt Service Routine)**:
```cpp
static void isrA(void *arg) {
    Motor *m = static_cast<Motor *>(arg);  // Recuperar objeto
    m->encoderChange(digitalRead(m->encA), digitalRead(m->encB));
}
```
- `static`: Necesario para que funcione como callback de interrupción
- `void *arg`: Puntero al objeto Motor
- Se ejecuta en cada flanco (CHANGE) del encoder

---

### Sección 3: Setup (Líneas 182-190)

```cpp
void setup() {
    Serial.begin(115200);
    motor1.init();
    motor2.init();
    motor3.init();
    motor4.init();
    Serial.println("Motores con encoder inicializados.");
}
```

**Proceso**:
1. Inicia comunicación serial a 115200 baudios
2. Inicializa cada motor (PWM + interrupciones)
3. Imprime confirmación

---

### Sección 4: Loop Principal (Líneas 210-236)

#### 1. Actualización de RPM

```cpp
motor1.updateRPM();
motor2.updateRPM();
motor3.updateRPM();
motor4.updateRPM();
```
- Se ejecuta en cada iteración
- Pero solo calcula RPM cada 500ms (internamente)

#### 2. Impresión de RPM

```cpp
if (millis() - lastPrint > 1000) {
    Serial.print("RPM1: "); Serial.print(motor1.getRPM());
    // ... (similar para otros motores)
    lastPrint = millis();
}
```
- Imprime RPM en monitor serial cada 1 segundo

#### 3. Ejemplo de Movimiento

```cpp
moverAdelante(200);  // Velocidad 200/255 (~78% del máximo)
delay(2000);         // Durante 2 segundos
detenerTodo();
delay(1000);
```

**Nota**: Este código de prueba debe reemplazarse por la lógica de lectura JSON para integración con ROS2.

---

### Sección 5: Integración JSON (Líneas 1-41)

Esta sección muestra cómo parsear comandos JSON:

```cpp
if (Serial.available()) {
    input = Serial.readStringUntil('\n');  // Leer hasta \n
    
    StaticJsonDocument<200> doc;
    DeserializationError error = deserializeJson(doc, input);
    
    if (!error) {
        int motor = doc["motor"];                 // Extraer campos
        const char *direccion = doc["direccion"];
        
        // Usar valores para controlar motores
    }
}
```

**Para integración completa**, deberías:

1. **Eliminar el código de prueba** (líneas 232-235)
2. **Agregar lógica de cinemática** para convertir `linear_speed` y `angular_speed` a velocidades individuales de cada motor
3. **Enviar feedback** en formato JSON

---

## Solución de Problemas

### El ESP32 no se conecta

```bash
# Verificar puerto
ls /dev/ttyUSB*

# Dar permisos
sudo chmod 666 /dev/ttyUSB0

# En Arduino IDE
# Herramientas → Puerto → Seleccionar el correcto
```

### Error al compilar

```
'ledcSetup' was not declared in this scope
```

**Solución**: Asegurarse de tener instalada la versión correcta del paquete ESP32 (2.0.x o superior).

### Los motores no se mueven

1. **Verificar alimentación**: Los motores necesitan 12V, el ESP32 solo 5V
2. **Revisar conexiones**: Verificar soldaduras y cables
3. **Medir con multímetro**: Comprobar voltaje en pines IN1/IN2 al enviar comandos
4. **Revisar drivers**: Los L8871 deben estar correctamente conectados y alimentados

### Encoders no cuentan pulsos

```cpp
// Añadir debug en ISR (solo temporalmente, las ISR deben ser rápidas)
void encoderChange(bool a, bool b) {
    pulsos += (a == b) ? 1 : -1;
    // Serial.println(pulsos);  // ¡SOLO PARA DEBUG! Quitar después
}
```

**Verificaciones**:
- Pull-ups activados: `pinMode(encA, INPUT_PULLUP)`
- Encoder alimentado (si lo requiere)
- Cables no intercambiados

### RPM siempre 0

1. **Motor no gira**: Revisar apartado anterior
2. **`updateRPM()` no se llama**: Verificar en loop()
3. **Constantes incorrectas**: 
   - `pulsosPorVuelta = 12` (para encoder de 12 PPR)
   - `reduccion = 80.0` (ajustar según tu motor)

### JSON no se parsea

```bash
# Probar en monitor serial
{"linear_speed": 100, "angular_speed": 0}

# Verificar terminador: debe ser \n (nueva línea)
# En Arduino IDE: Config. monitor → "Nueva Línea"
```

---

## Próximos Pasos

### Mejoras Sugeridas

1. **Control PID**: Implementar lazo cerrado para mantener velocidad constante
2. **Cinemática inversa**: Calcular velocidades individuales de ruedas según `linear_speed` y `angular_speed`
3. **Odometría**: Calcular posición del robot basada en encoders
4. **Limitación de corriente**: Proteger motores y drivers
5. **Watchdog**: Detener motores si no recibe comandos por X tiempo

### Ejemplo de Cinemática (4 ruedas omnidireccionales)

```cpp
// Configuración en X
void calcularVelocidadesMotores(float vx, float vy, float omega) {
    float v1 = vx - vy - omega * L;
    float v2 = vx + vy - omega * L;
    float v3 = vx + vy + omega * L;
    float v4 = vx - vy + omega * L;
    
    // Escalar y aplicar a motores
    motor1.forward(abs(v1)); // Agregar lógica de dirección
    // ...
}
```

---

## Recursos

- **ESP32 PWM**: https://randomnerdtutorials.com/esp32-pwm-arduino-ide/
- **ArduinoJson**: https://arduinojson.org/v6/doc/
- **Encoders cuadráticos**: https://howtomechatronics.com/tutorials/arduino/rotary-encoder-works-use-arduino/
- **Control de motores**: https://www.electronicwings.com/esp32/dc-motor-interfacing-with-esp32

---

## Licencia

MIT License

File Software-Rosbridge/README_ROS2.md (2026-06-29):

# 📑 Documentación de ejecución de ROS2 en Raspberry Pi

A continuación se describen los pasos y comandos necesarios para conectarse a la Raspberry Pi y lanzar los nodos principales de ROS2 utilizados en el proyecto.

---

## 1. Conexión remota vía SSH  
El primer paso es establecer la conexión remota con la Raspberry Pi desde otro equipo (ej. portátil).  
Esto se logra con el comando:  

```bash
ssh raspi@192.168.0.108
```

- `ssh`: protocolo de conexión segura a otro dispositivo.  
- `raspi`: usuario configurado en la Raspberry Pi.  
- `192.168.0.108`: dirección IP de la Raspberry Pi dentro de la red local.  

---

## 2. Acceso al directorio del workspace  
Una vez dentro de la Raspberry Pi, se debe moverse al directorio donde se encuentra el workspace de ROS2.  

```bash
cd swarmROS/src
```

- `cd`: comando para cambiar de directorio.  
- `swarmROS/src`: ruta en donde se encuentran los paquetes ROS2 del proyecto.  

---

## 3. Lanzar el nodo del LIDAR  
El siguiente paso es iniciar el nodo correspondiente al sensor **LD19 LIDAR**.  

```bash
ros2 launch ld19_lidar lidar.launch.py
```

- `ros2 launch`: comando para iniciar un *launch file* de ROS2.  
- `ld19_lidar`: paquete ROS2 que contiene la configuración del LIDAR.  
- `lidar.launch.py`: archivo de lanzamiento que inicia los nodos necesarios para operar el sensor.  

---

## 4. Lanzar el servidor Rosbridge  
Finalmente, se levanta el servidor **Rosbridge**, el cual permite la comunicación entre ROS2 y aplicaciones externas (ej. aplicaciones web vía WebSocket).  

```bash
ros2 launch rosbridge_server rosbridge_websocket_launch.xml
```

- `ros2 launch`: inicia un *launch file*.  
- `rosbridge_server`: paquete encargado de abrir el servidor de comunicación.  
- `rosbridge_websocket_launch.xml`: archivo de configuración que habilita el acceso a través de WebSockets.  

---

✅ Con estos pasos, la Raspberry Pi queda lista para:  
- Recibir datos del LIDAR.  
- Exponerlos mediante **Rosbridge** para que otros clientes puedan conectarse (por ejemplo, una interfaz web o aplicaciones de monitoreo).

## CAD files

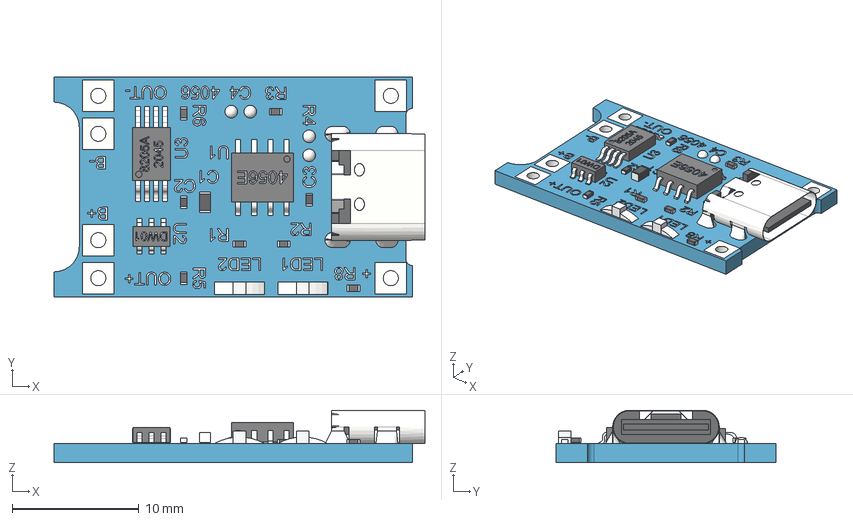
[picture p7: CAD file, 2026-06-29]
Control SWARM unicapa/tp4056-charging-module-2.snapshot.1/TP4056_Charging_Module_Type_C.step
29.3 x 17.4 x 4.14 mm
board
USB_Type_C_Connector
8205A_2045
DW01-P
small1005_smd_resistor x 2
small1005_smd_resistor (1)
small1005_smd_capacitor
smd_capacitor
SOP-8_4056E
solder_dot_round
solder_dot_round (1)
solder_dot_round (2)
solder_dot_round (3)
small1005_smd_capacitor (1)
LED2
LED2 (1)
small1005_smd_resistor (2)
small1005_smd_resistor (4) x 2
soldering

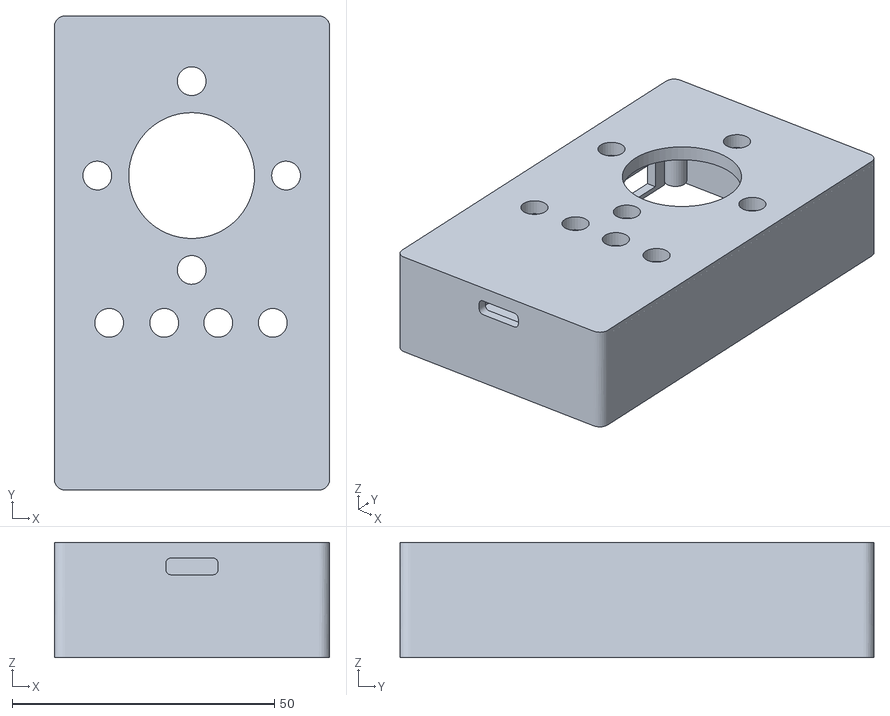
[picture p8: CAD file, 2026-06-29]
Control SWARM unicapa/upper_print.stl
52.5 x 90.4 x 22.0

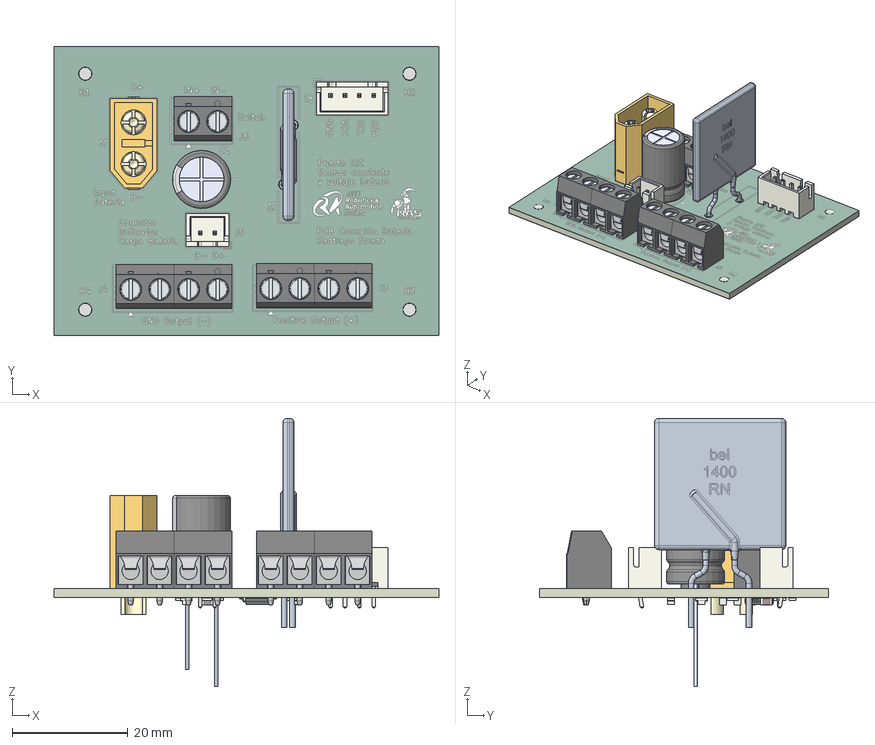
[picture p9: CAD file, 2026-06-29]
Electrónica/Placa Potencia Piso 1 Impresa.step
66.5 x 50.0 x 46.4 mm
ECA1CM102
0ZRN1400FF1A_PART1
0ZRN1400FF1A_PART2
0ZRN1400FF1A_PART3
0ZRN1400FF1A_PART4
JST_XH_B2B-XH-A_1x02_P2.50mm_Vertical
AMASS_XT60-M_1x02_P7.2mm_Vertical
JST_XH_B4B-XH-A_1x04_P2.50mm_Vertical
R_0805_2012Metric x 6
C_0805_2012Metric x 3
LED_0805_2012Metric x 2
TSSOP-16_4.4x5mm_P0.65mm
piso 1 pcb power_copper
piso 1 pcb power_pad
piso 1 pcb power_silkscreen x 2
piso 1 pcb power_soldermask x 2
piso 1 pcb power_PCB

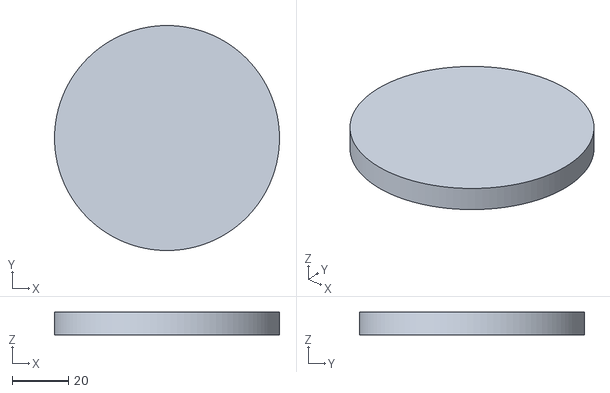
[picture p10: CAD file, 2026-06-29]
ROS_2026/src/SWARM_description/meshes/lidar_1.stl
80.0 x 80.0 x 8.00

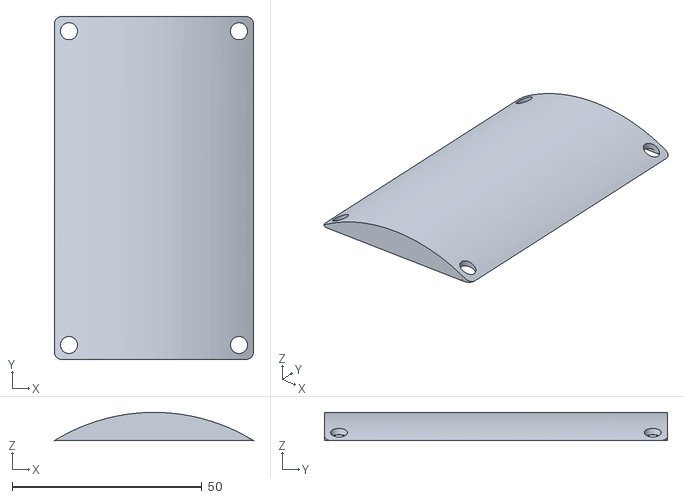
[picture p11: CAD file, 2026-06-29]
Control SWARM unicapa/lower_print.stl
52.5 x 90.4 x 7.45

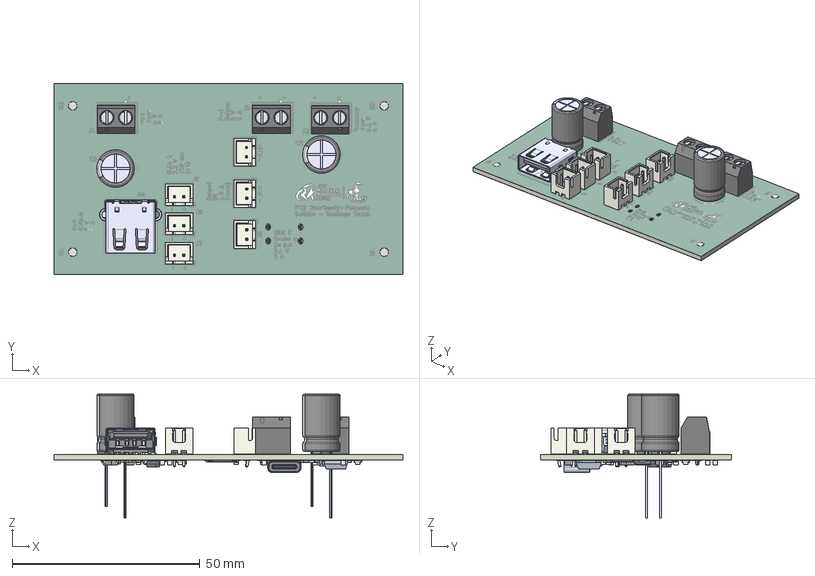
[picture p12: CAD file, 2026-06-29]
Electrónica/Placa Potencia Piso 2 Impresa.step
93.0 x 51.0 x 33.0 mm
JST_XH_B2B-XH-A_1x02_P2.50mm_Vertical x 6
ECA1CM102 x 2
USB1130-15-A_REVA
0ZCF0700FF2C_PART1 x 8
0ZCF0700FF2C_PART2 x 8
0ZCF0700FF2C_PART3 x 8
0ZCF0700FF2C_PART4 x 8
0ZCF0700FF2C_PART5 x 8
0ZCF0700FF2C_PART6 x 4
0ZCF0700FF2C_PART7 x 4
0ZCF0700FF2C_PART8 x 4
0ZCF0700FF2C_PART9 x 4
0ZCF0700FF2C_PART10 x 4
0ZCF0700FF2C_PART11 x 4
0ZCF0700FF2C_PART12 x 4
0ZCF0700FF2C_PART13 x 4
0ZCF0700FF2C_PART14 x 4
C_0805_2012Metric x 18
R_0805_2012Metric x 11
.step 1.20.1
TPS25751SRSMR--3DModel-STEP-56544
LED_0805_2012Metric x 8
USB4125-GF-A_REVA2
PICOSMDC050S-2 x 2
R_2512_6332Metric
R_0603_1608Metric
SOT-223
Placa_Poder_Piso2_copper
Placa_Poder_Piso2_pad
Placa_Poder_Piso2_via
Placa_Poder_Piso2_silkscreen x 2
Placa_Poder_Piso2_soldermask x 2
Placa_Poder_Piso2_PCB

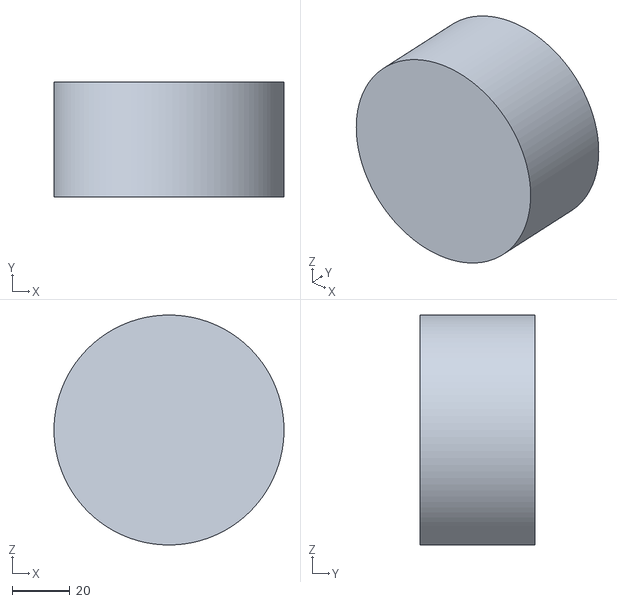
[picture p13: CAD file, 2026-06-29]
ROS_2026/src/SWARM_description/meshes/right_wheel_1.stl
80.0 x 40.0 x 80.0

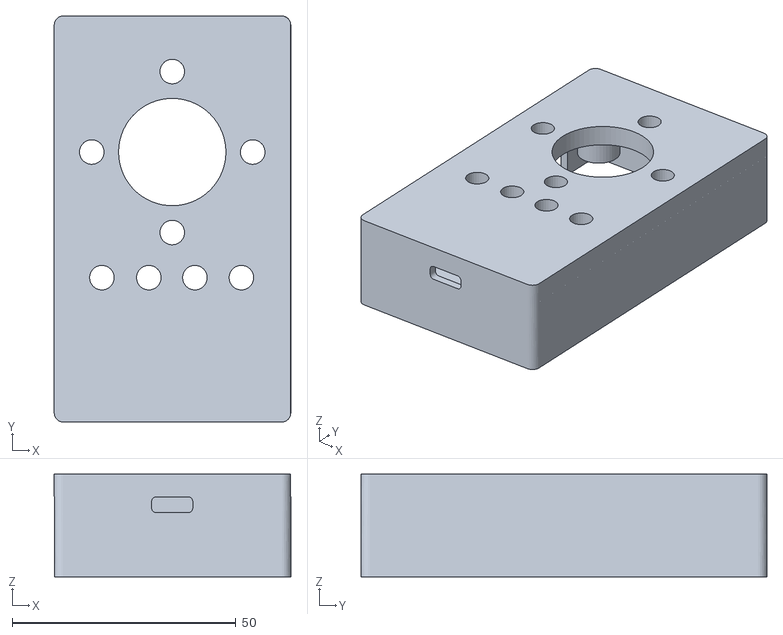
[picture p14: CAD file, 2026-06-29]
Control SWARM unicapa/lid_case.stl
52.9 x 90.8 x 23.0

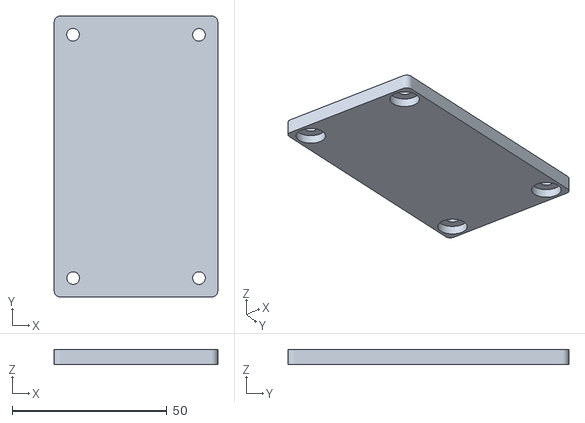
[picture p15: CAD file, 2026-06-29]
Control SWARM unicapa/bottom_case.stl
52.9 x 90.8 x 5.00

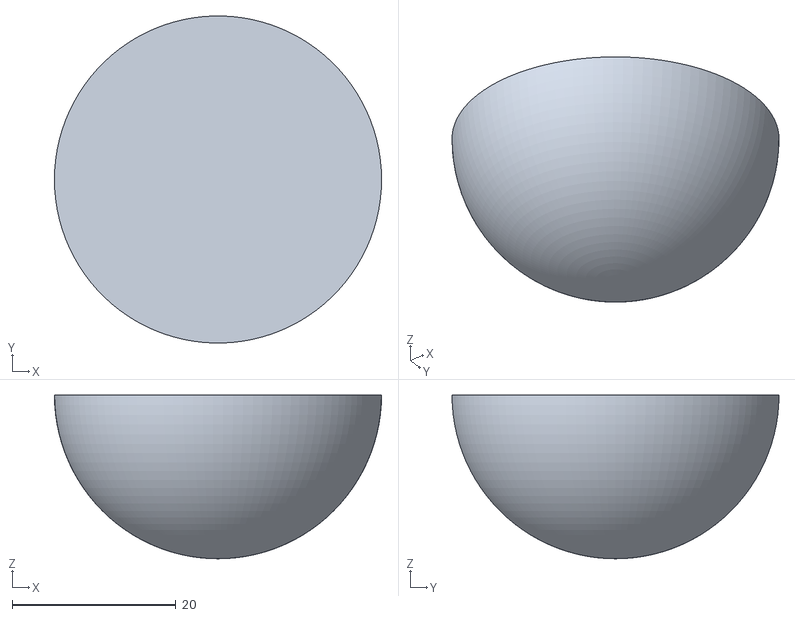
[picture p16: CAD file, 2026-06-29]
ROS_2026/src/SWARM_description/meshes/front_caster_1.stl
40.0 x 40.0 x 20.0

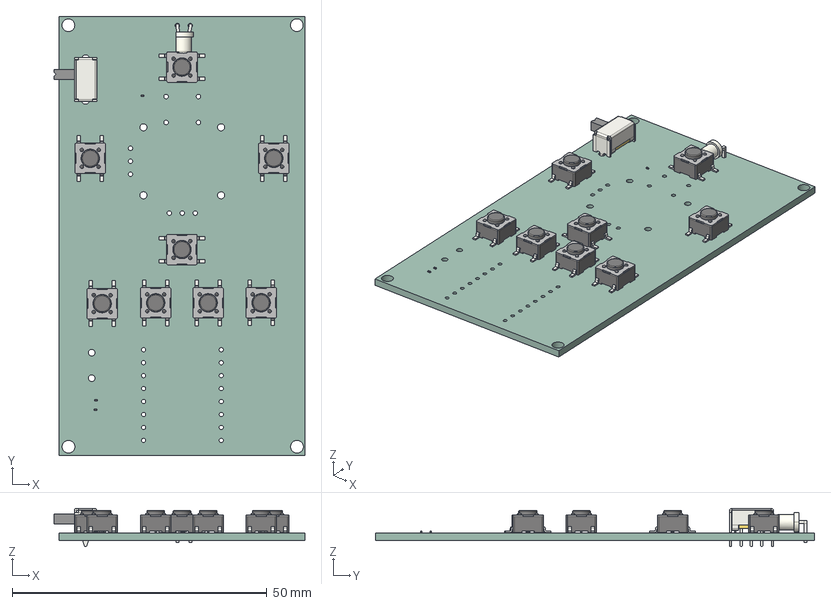
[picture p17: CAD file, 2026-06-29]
Control SWARM unicapa/Control SWARM.step
49.2 x 86.2 x 7.50 mm
R_0201_0603Metric x 12
SW_SPST_PTS645Sx43SMTR92 x 8
SW_Slide_SPDT_Angled_CK_OS102011MA1Q
LED_D3.0mm_Horizontal_O1.27mm_Z2.0mm_Clear
Control SWARM_PCB

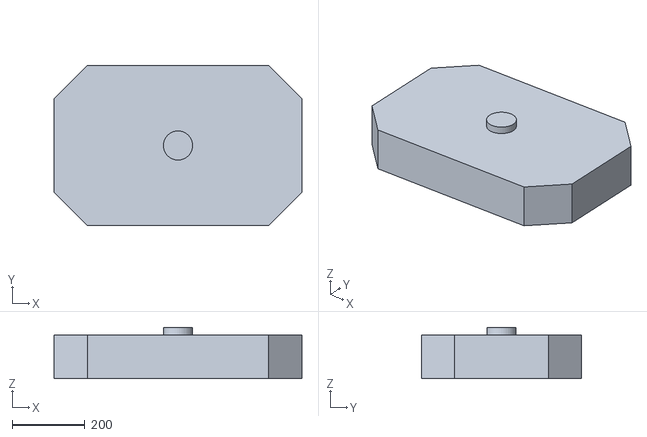
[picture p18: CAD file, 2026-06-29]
ROS_2026/src/SWARM_description/meshes/base_link.stl
680.0 x 440.0 x 140.0

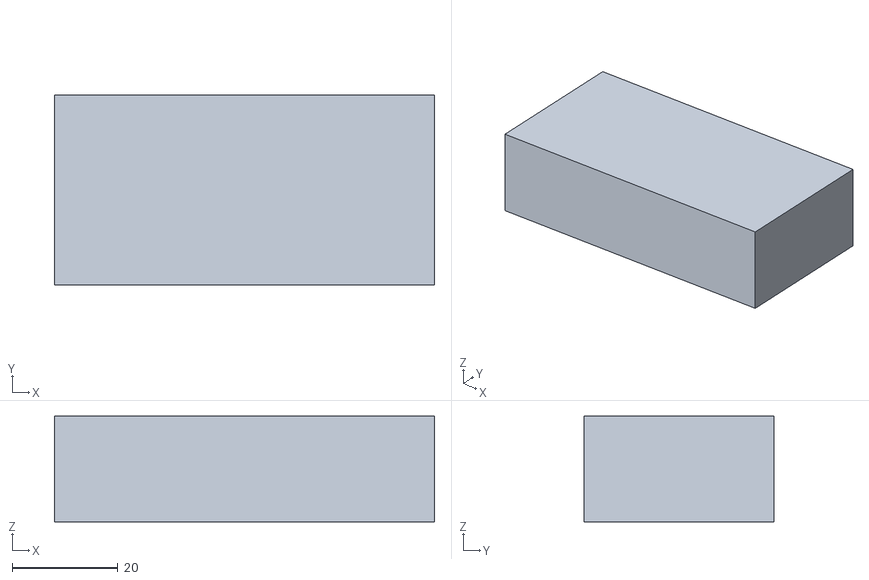
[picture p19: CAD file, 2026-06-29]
ROS_2026/src/SWARM_description/meshes/camera_1.stl
72.0 x 36.0 x 20.0

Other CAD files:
ROS_2026/src/SWARM_description/meshes/left_wheel_1.stl
ROS_2026/src/SWARM_description/meshes/back_caster_1.stl
Control SWARM unicapa/Control SWARM.stl
Control SWARM unicapa/tp4056-charging-module-2.snapshot.1/TP4056_Charging_Module_Type_C.f3d

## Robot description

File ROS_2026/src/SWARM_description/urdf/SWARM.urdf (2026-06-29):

<?xml version="1.0" ?>
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
<robot name="SWARM">
  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
  <link name="base_link">
    <inertial>
      <origin rpy="0 0 0" xyz="4.4051457261675034e-14 1.6159784892526872e-07 0.015304612648961219"/>
      <mass value="1.7568667863343854"/>
      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
    </inertial>
    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
  </link>
  <link name="lidar_1">
    <inertial>
      <origin rpy="0 0 0" xyz="0.0 6.938893903907229e-19 0.000999999999999987"/>
      <mass value="0.004932300466135958"/>
      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
    </inertial>
    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
  </link>
  <link name="camera_1">
    <inertial>
      <origin rpy="0 0 0" xyz="1.3877787807814458e-18 0.0050000000000000044 0.0025000000000000022"/>
      <mass value="0.006358499999999989"/>
      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
    </inertial>
    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
  </link>
  <link name="front_caster_1">
    <inertial>
      <origin rpy="0 0 0" xyz="0.0 0.02500000000000001 -0.001875"/>
      <mass value="0.0020551251942233233"/>
      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
    </inertial>
    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
  </link>
  <link name="back_caster_1">
    <inertial>
      <origin rpy="0 0 0" xyz="-4.163336342344337e-18 -0.02500000000000001 -0.001875"/>
      <mass value="0.0020551251942233233"/>
      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
    </inertial>
    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
  </link>
  <link name="left_wheel_1">
    <inertial>
      <origin rpy="0 0 0" xyz="0.0050000000000000044 2.019136008197186e-08 3.451916907610403e-08"/>
      <mass value="0.024661502330679874"/>
      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
    </inertial>
    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
  </link>
  <link name="right_wheel_1">
    <inertial>
      <origin rpy="0 0 0" xyz="-0.005000000000000011 2.019136008197186e-08 3.451916907610403e-08"/>
      <mass value="0.024661502330679874"/>
      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
    </inertial>
    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
  </link>
  <joint name="lidar_joint" type="fixed">
    <origin rpy="0 0 0" xyz="0.0 0.0 0.035"/>
    <parent link="base_link"/>
    <child link="lidar_1"/>
  </joint>
  <joint name="camera_joint" type="fixed">
    <origin rpy="0 0 0" xyz="0.0 -0.085 0.03"/>
    <parent link="base_link"/>
    <child link="camera_1"/>
  </joint>
  <joint name="front_caster_joint" type="fixed">
    <origin rpy="0 0 0" xyz="0.0 -0.085 0.0"/>
    <parent link="base_link"/>
    <child link="front_caster_1"/>
  </joint>
  <joint name="back_caster_joint" type="fixed">
    <origin rpy="0 0 0" xyz="0.0 0.085 0.0"/>
    <parent link="base_link"/>
    <child link="back_caster_1"/>
  </joint>
  <joint name="left_wheel_joint" type="continuous">
    <origin rpy="0 0 0" xyz="0.03 -6.3e-05 0.00502"/>
    <parent link="base_link"/>
    <child link="left_wheel_1"/>
    <axis xyz="1.0 0.0 0.0"/>
  </joint>
  <joint name="right_wheel_joint" type="continuous">
    <origin rpy="0 0 0" xyz="-0.03 -6.3e-05 0.00502"/>
    <parent link="base_link"/>
    <child link="right_wheel_1"/>
    <axis xyz="-1.0 0.0 0.0"/>
  </joint>
</robot>

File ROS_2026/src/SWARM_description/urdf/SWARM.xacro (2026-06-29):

<?xml version="1.0" ?>
<robot name="SWARM" xmlns:xacro="http://www.ros.org/wiki/xacro">

<xacro:include filename="$(find SWARM_description)/urdf/materials.xacro" />
<xacro:include filename="$(find SWARM_description)/urdf/SWARM.ros2control" />
<xacro:include filename="$(find SWARM_description)/urdf/SWARM.gazebo" />

<link name="base_footprint"/>

<joint name="base_footprint_joint" type="fixed">
  <origin xyz="0 0 0" rpy="0 0 0"/>
  <parent link="base_footprint"/>
  <child link="base_link"/>
</joint>

<link name="base_link">
  <inertial>
    <origin xyz="-6.463913954572466e-07 0.0 0.061218450595844895" rpy="0 0 0"/>
    <mass value="12.43947432540084"/>
    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
  </inertial>
  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
</link>

<link name="lidar_1">
  <inertial>
    <origin xyz="-2.220446049250313e-18 -1.3877787807814457e-19 0.003999999999999976" rpy="0 0 0"/>
    <mass value="0.3156672298327027"/>
    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
  </inertial>
  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
</link>

<link name="camera_1">
  <inertial>
    <origin xyz="-0.030000000000000082 -7.105427357601002e-17 0.010000000000000009" rpy="0 0 0"/>
    <mass value="0.4069439999999993"/>
    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
  </inertial>
  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
</link>

<link name="front_caster_1">
  <inertial>
    <origin xyz="-0.07 -7.105427357601002e-17 -0.0075" rpy="0 0 0"/>
    <mass value="0.1315280124302927"/>
    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
  </inertial>
  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
</link>

<link name="back_caster_1">
  <inertial>
    <origin xyz="0.07 5.134781488891349e-17 -0.007500000000000004" rpy="0 0 0"/>
    <mass value="0.1315280124302927"/>
    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
  </inertial>
  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
</link>

<link name="left_wheel_1">
  <inertial>
    <origin xyz="-8.076544029899345e-08 0.020000000000000018 1.380766763044161e-07" rpy="0 0 0"/>
    <mass value="1.5783361491635122"/>
    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
  </inertial>
  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
</link>

<link name="right_wheel_1">
  <inertial>
    <origin xyz="-8.076544036334085e-08 -0.01999999999999999 1.3807667632176335e-07" rpy="0 0 0"/>
    <mass value="1.578336149163511"/>
    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
  </inertial>
  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
</link>

<joint name="lidar_joint" type="fixed">
  <origin xyz="0.0 0.0 0.14" rpy="0 0 0"/>
  <parent link="base_link"/>
  <child link="lidar_1"/>
</joint>

<joint name="camera_joint" type="fixed">
  <origin xyz="0.34 0.0 0.12" rpy="0 0 0"/>
  <parent link="base_link"/>
  <child link="camera_1"/>
</joint>

<joint name="front_caster_joint" type="fixed">
  <origin xyz="0.34 0.0 0.01" rpy="0 0 0"/>
  <parent link="base_link"/>
  <child link="front_caster_1"/>
</joint>

<joint name="back_caster_joint" type="fixed">
  <origin xyz="-0.34 0.0 0.01" rpy="0 0 0"/>
  <parent link="base_link"/>
  <child link="back_caster_1"/>
</joint>

<joint name="left_wheel_joint" type="continuous">
  <origin xyz="0.000252 0.12 0.02008" rpy="0 0 0"/>
  <parent link="base_link"/>
  <child link="left_wheel_1"/>
  <axis xyz="0.0 1.0 0.0"/>
</joint>

<joint name="right_wheel_joint" type="continuous">
  <origin xyz="0.000252 -0.12 0.02008" rpy="0 0 0"/>
  <parent link="base_link"/>
  <child link="right_wheel_1"/>
  <axis xyz="0.0 1.0 0.0"/>
</joint>

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

</robot>

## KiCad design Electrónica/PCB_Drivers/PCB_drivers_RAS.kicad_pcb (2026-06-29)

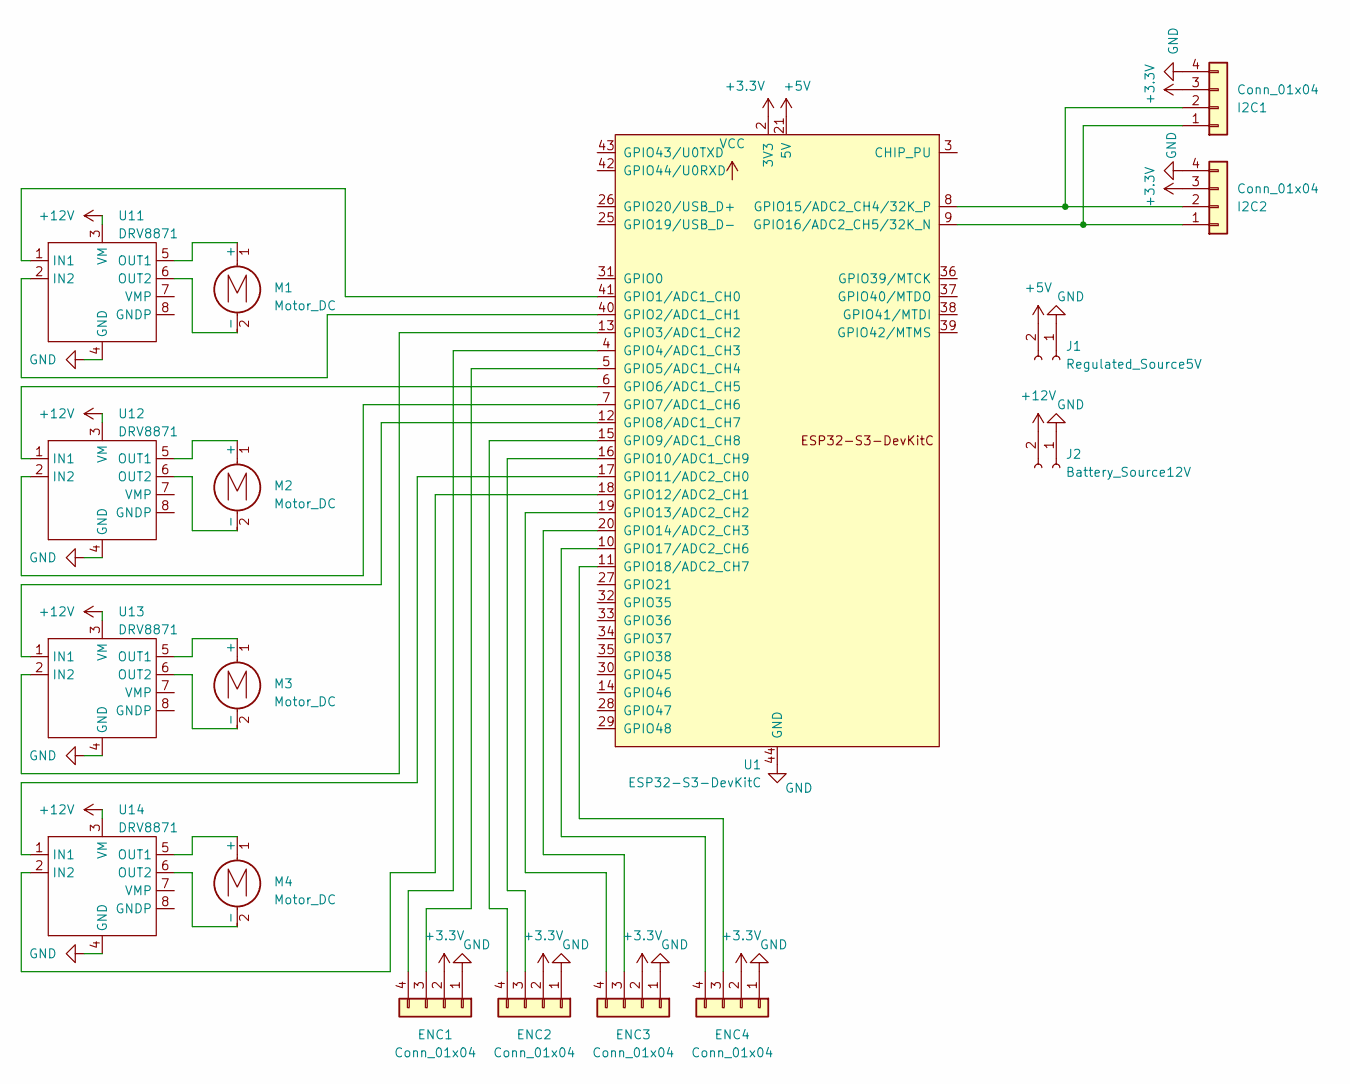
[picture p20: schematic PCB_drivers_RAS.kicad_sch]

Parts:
ENC1, ENC2, ENC3, ENC4: Conn_01x04; PinSocket_1x04_P2.54mm_Vertical
I2C1, I2C2: Conn_01x04; PinSocket_1x04_P2.54mm_Vertical
J1: Regulated_Source5V; PinSocket_1x02_P2.00mm_Vertical
J2: Battery_Source12V; PinSocket_1x02_P2.54mm_Vertical
M1, M2, M3, M4: Motor_DC; PinHeader_2x01_P2.54mm_Vertical
U1: ESP32-S3-DevKitC
U11, U12, U13, U14: DRV8871; DRV8871-MODULE

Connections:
+3.3V: ENC1.2, ENC2.2, ENC3.2, ENC4.2, I2C1.3, I2C2.3, U1.1 (3V3), U1.2 (3V3)
+5V: J1.2, U1.21 (5V)
+12V: J2.2, U11.3 (VM), U12.3 (VM), U13.3 (VM), U14.3 (VM)
GND: ENC1.1, ENC2.1, ENC3.1, ENC4.1, I2C1.4, I2C2.4, J1.1, J2.1, U1.22 (GND), U1.23 (GND), U1.24 (GND), U1.44 (GND), U11.4 (GND), U12.4 (GND), U13.4 (GND), U14.4 (GND)
unnamed: ENC1.3, U1.5 (GPIO5/ADC1_CH4)
unnamed: ENC1.4, U1.4 (GPIO4/ADC1_CH3)
unnamed: ENC2.3, U1.16 (GPIO10/ADC1_CH9)
unnamed: ENC2.4, U1.15 (GPIO9/ADC1_CH8)
unnamed: ENC3.3, U1.20 (GPIO14/ADC2_CH3)
unnamed: ENC3.4, U1.19 (GPIO13/ADC2_CH2)
unnamed: ENC4.3, U1.11 (GPIO18/ADC2_CH7)
unnamed: ENC4.4, U1.10 (GPIO17/ADC2_CH6)
unnamed: I2C1.1, I2C2.1, U1.9 (GPIO16/ADC2_CH5/32K_N)
unnamed: I2C1.2, I2C2.2, U1.8 (GPIO15/ADC2_CH4/32K_P)
unnamed: M1.1 (+), U11.5 (OUT1)
unnamed: M1.2 (-), U11.6 (OUT2)
unnamed: M2.1 (+), U12.5 (OUT1)
unnamed: M2.2 (-), U12.6 (OUT2)
unnamed: M3.1 (+), U13.5 (OUT1)
unnamed: M3.2 (-), U13.6 (OUT2)
unnamed: M4.1 (+), U14.5 (OUT1)
unnamed: M4.2 (-), U14.6 (OUT2)
unnamed: U1.41 (GPIO1/ADC1_CH0), U11.1 (IN1)
unnamed: U1.40 (GPIO2/ADC1_CH1), U11.2 (IN2)
unnamed: U1.13 (GPIO3/ADC1_CH2), U13.2 (IN2)
unnamed: U1.6 (GPIO6/ADC1_CH5), U12.1 (IN1)
unnamed: U1.7 (GPIO7/ADC1_CH6), U12.2 (IN2)
unnamed: U1.12 (GPIO8/ADC1_CH7), U13.1 (IN1)
unnamed: U1.17 (GPIO11/ADC2_CH0), U14.1 (IN1)
unnamed: U1.18 (GPIO12/ADC2_CH1), U14.2 (IN2)

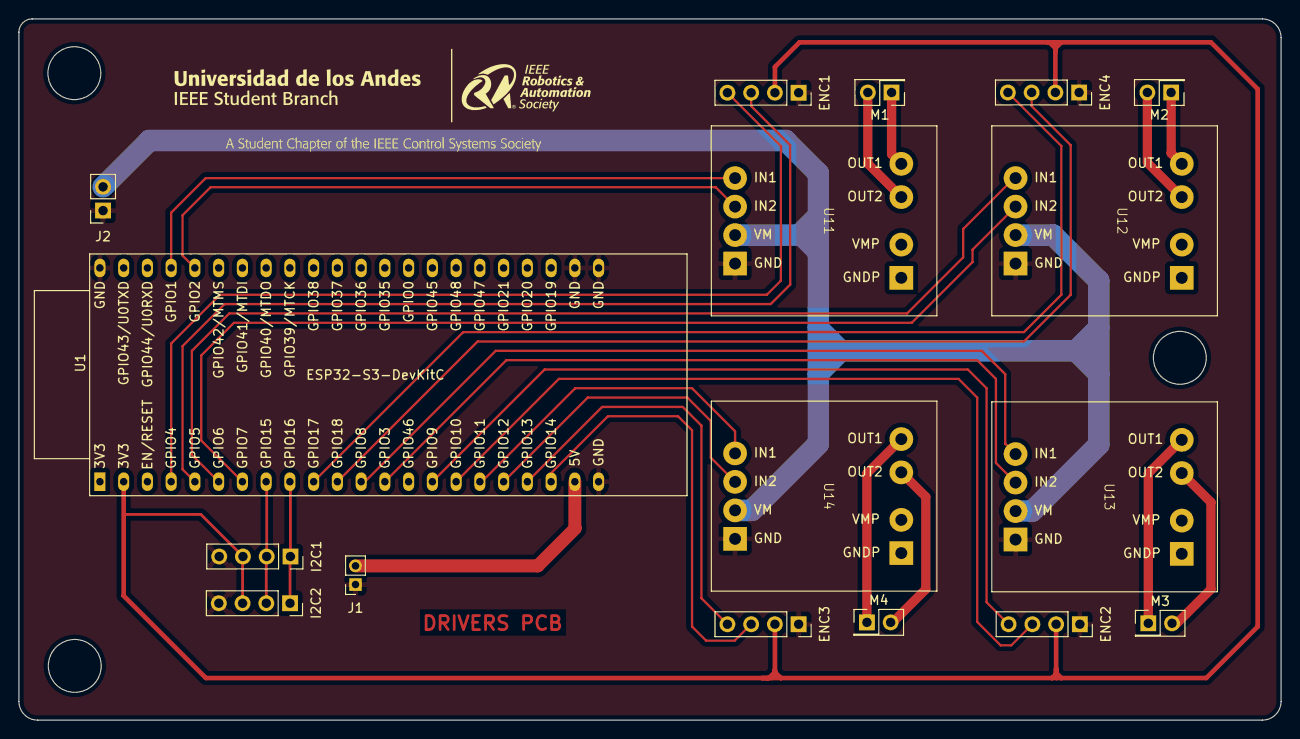
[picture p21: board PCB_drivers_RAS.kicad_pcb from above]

Board: 2 copper layers, 135.0 x 75.0 mm, 17 parts (0 on the bottom side), 30 nets.

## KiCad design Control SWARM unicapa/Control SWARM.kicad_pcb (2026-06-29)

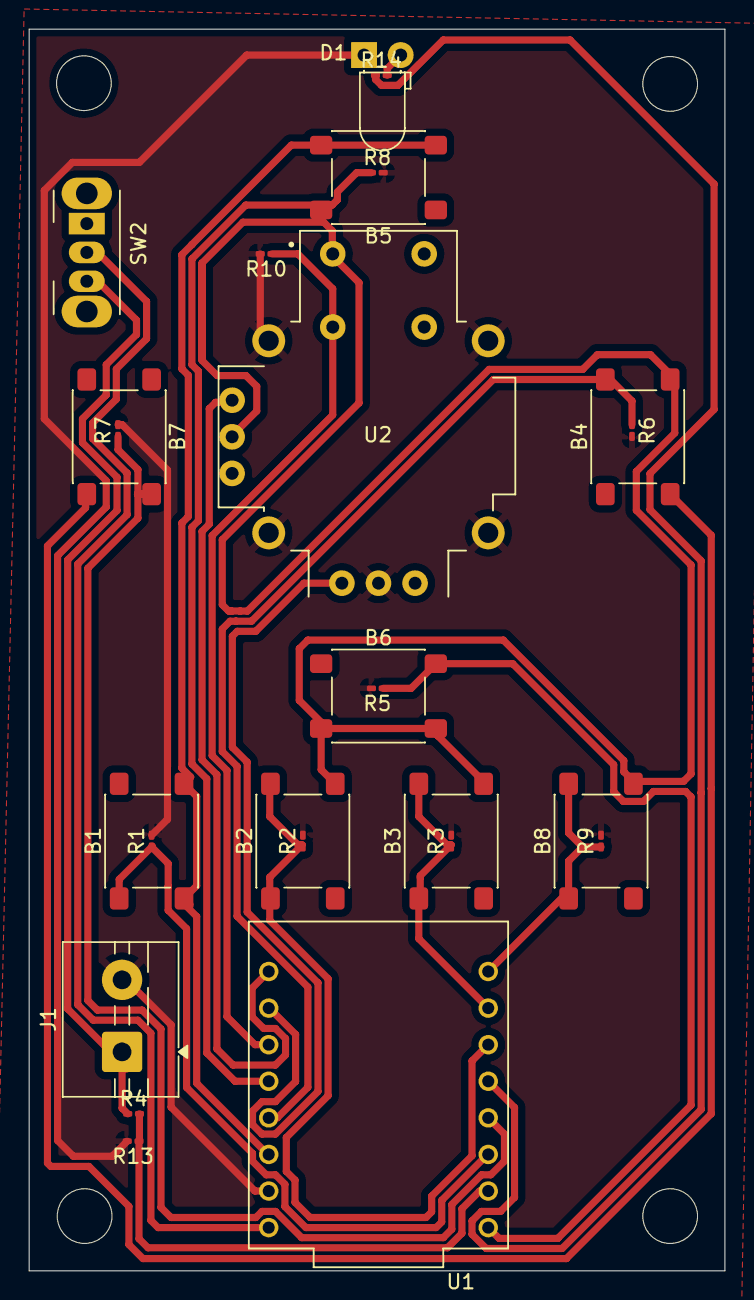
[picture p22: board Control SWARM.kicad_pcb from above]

Board: 2 copper layers, 48.3 x 86.2 mm, 25 parts (0 on the bottom side), 18 nets.

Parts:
B1: Line Button 1; SW_SPST_PTS645Sx43SMTR92
B2: Line Button 2; SW_SPST_PTS645Sx43SMTR92
B3: Line Button 3; SW_SPST_PTS645Sx43SMTR92
B4: Radial Button 2; SW_SPST_PTS645Sx43SMTR92
B5: Radial Button 1; SW_SPST_PTS645Sx43SMTR92
B6: Radial Button 3; SW_SPST_PTS645Sx43SMTR92
B7: Radial Button 4; SW_SPST_PTS645Sx43SMTR92
B8: Line Button 4; SW_SPST_PTS645Sx43SMTR92
D1: LED; LED_D3.0mm_Horizontal_O1.27mm_Z2.0mm_Clear
J1: Screw_Terminal_01x02; TerminalBlock_MaiXu_MX126-5.0-02P_1x02_P5.00mm
R1: RL1; R_0201_0603Metric_Pad0.64x0.40mm_HandSolder
R2: RL2; R_0201_0603Metric_Pad0.64x0.40mm_HandSolder
R3: RL3; R_0201_0603Metric_Pad0.64x0.40mm_HandSolder
R4: RVD1; R_0201_0603Metric_Pad0.64x0.40mm_HandSolder
R5: RR3; R_0201_0603Metric_Pad0.64x0.40mm_HandSolder
R6: RR2; R_0201_0603Metric_Pad0.64x0.40mm_HandSolder
R7: RR4; R_0201_0603Metric_Pad0.64x0.40mm_HandSolder
R8, R10: RR1; R_0201_0603Metric_Pad0.64x0.40mm_HandSolder
R9: RL4; R_0201_0603Metric_Pad0.64x0.40mm_HandSolder
R13: RVD2; R_0201_0603Metric_Pad0.64x0.40mm_HandSolder
R14: LEDR; R_0201_0603Metric_Pad0.64x0.40mm_HandSolder
SW2: SW_SPDT; SW_Slide_SPDT_Angled_CK_OS102011MA1Q
U1: ESP32-C3_MINI; MODULE_ESP32-C3_SUPERMINI_TH
U2: JOYSTICK; XDCR_COM-09032

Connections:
+3.3V: B1.2, B2.2, B3.2, B4.2, B5.2, B6.2, B7.2, B8.2, U1.3.3 (3V3), U2.B1A (SEL+), U2.V2 (V)
+3.6V: J1.1, R4.1, SW2.3 (C)
/GPIO0 A0: U1.0 (GPIO0), U2.V1 (V+)
/GPIO1 A1: U1.1 (GPIO1), U2.H1 (H+)
/GPIO2 A2: R10.1, U1.2 (GPIO2), U2.B2A (SEL-)
/GPIO3 A3: B5.1, R8.1, U1.3 (GPIO3)
/GPIO4 A4 SCK: B4.1, R6.1, U1.4 (GPIO4)
/GPIO5 A5 MISO: B6.1, R5.1, U1.5 (GPIO5)
/GPIO6 MOSI: R4.2, R13.1, U1.6 (GPIO6)
/GPIO7 SS: B1.1, R1.1, U1.7 (GPIO7)
/GPIO8 SDA: B7.1, R7.1, U1.8 (GPIO8)
/GPIO9 SCL: R14.1, U1.9 (GPIO9)
/GPIO10: B2.1, R2.1, U1.10 (GPIO10)
/GPIO20 RX: B3.1, R3.1, U1.20 (GPIO20)
/GPIO21 TX: B8.1, R9.1, U1.21 (GPIO21)
/VOLTAGE REGULATED: SW2.2 (B), U1.5V
GND: D1.1 (K), J1.2, R1.2, R2.2, R3.2, R5.2, R6.2, R7.2, R8.2, R9.2, R10.2, R13.2, U1.G (GND), U2.H2 (H), U2.S1 (SHIELD), U2.S2 (SHIELD), U2.S3 (SHIELD), U2.S4 (SHIELD)
unnamed: D1.2 (A), R14.2

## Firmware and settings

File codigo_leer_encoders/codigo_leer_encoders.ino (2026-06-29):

#include <WiFi.h>
#include <ESPAsyncWebServer.h>

// =========================
// WiFi
// =========================
const char *ssid = "SSID-HERE";
const char *password = "PASSWORD-HERE";

AsyncWebServer server(80);

// =========================
// Pines del encoder
// =========================
#define EncoderPinA 4
#define EncoderPinB 5

volatile long ticksEncoder1 = 0;

// =========================
// Pines del motor
// =========================
#define motor1A 8
#define motor1B 7
#define motor1_PWM 9

// =========================
// Configuración PWM
// =========================
// En ESP32 normalmente es mejor usar LEDC
const int pwmChannel = 0;
const int pwmFreq = 20000;
const int pwmResolution = 8;   // rango 0 a 255

const int PWM_BAJO = 90;
const int PWM_ALTO = 200;

// =========================
// Variables de velocidad
// =========================
unsigned long tAnterior = 0;
const unsigned long periodo = 100;   // ms

float omega = 0.0;
float rpm = 0.0;

long ticksPrevios = 0;

String estadoMotor = "Detenido";
int pwmActual = 0;

// =========================
// ISR encoder
// =========================
void IRAM_ATTR Encoder1A_ISR() {
  if (digitalRead(EncoderPinB) == HIGH) {
    ticksEncoder1++;
  } else {
    ticksEncoder1--;
  }
}

// =========================
// Funciones de motor
// =========================
void motorAdelante(int pwm) {
  digitalWrite(motor1A, HIGH);
  digitalWrite(motor1B, LOW);
  estadoMotor = "Adelante";
  pwmActual = pwm;
}

void motorAtras(int pwm) {
  digitalWrite(motor1A, LOW);
  digitalWrite(motor1B, HIGH);
  estadoMotor = "Atrás";
  pwmActual = pwm;
}

void motorDetener() {
  digitalWrite(motor1A, LOW);
  digitalWrite(motor1B, LOW);
  estadoMotor = "Detenido";
  pwmActual = 0;
}

// =========================
// Página web
// =========================
String paginaHTML() {
  long ticksCopia;
  noInterrupts();
  ticksCopia = ticksEncoder1;
  interrupts();

  String html = "<!DOCTYPE html><html><head>";
  html += "<meta charset='UTF-8'>";
  html += "<meta name='viewport' content='width=device-width, initial-scale=1.0'>";
  html += "<meta http-equiv='refresh' content='2'>";
  html += "<title>Control Motor DC</title>";
  html += "</head><body>";

  html += "<h1>Control Motor DC por WiFi</h1>";
  html += "<p><a href=\"/forward500\"><button>Adelante baja</button></a></p>";
  html += "<p><a href=\"/forward2000\"><button>Adelante alta</button></a></p>";
  html += "<p><a href=\"/backward500\"><button>Atras baja</button></a></p>";
  html += "<p><a href=\"/backward2000\"><button>Atras alta</button></a></p>";
  html += "<p><a href=\"/stop\"><button>Detener</button></a></p>";

  html += "<hr>";
  html += "<p><b>Estado:</b> " + estadoMotor + "</p>";
  html += "<p><b>PWM actual:</b> " + String(pwmActual) + "</p>";
  html += "<p><b>Ticks acumulados:</b> " + String(ticksCopia) + "</p>";
  html += "<p><b>RPM:</b> " + String(rpm, 2) + "</p>";
  html += "<p><b>Omega:</b> " + String(omega, 2) + " rad/s</p>";

  html += "</body></html>";
  return html;
}

void setup() {
  Serial.begin(115200);

  // =========================
  // Configuración del encoder
  // =========================
  pinMode(EncoderPinA, INPUT_PULLUP);
  pinMode(EncoderPinB, INPUT_PULLUP);

  attachInterrupt(digitalPinToInterrupt(EncoderPinA), Encoder1A_ISR, RISING);

  tAnterior = millis();

  // =========================
  // Configuración del motor
  // =========================
  pinMode(motor1A, OUTPUT);
  pinMode(motor1B, OUTPUT);


  motorDetener();

  // =========================
  // Conexión WiFi
  // =========================
  WiFi.begin(ssid, password);
  while (WiFi.status() != WL_CONNECTED) {
    delay(1000);
    Serial.println("Connecting to WiFi...");
  }

  Serial.println("Connected to WiFi");
  Serial.println("");
  Serial.print("Connected to ");
  Serial.println(ssid);
  Serial.print("IP address: http://");
  Serial.println(WiFi.localIP());

  // =========================
  // Rutas del servidor - Ni idea si asi es como lo vamos a hacer.
  // =========================
  server.on("/", HTTP_GET, [](AsyncWebServerRequest *request) {
    request->send(200, "text/html", paginaHTML());
  });

  server.on("/forward500", HTTP_GET, [](AsyncWebServerRequest *request) {
    motorAdelante(PWM_BAJO);
    request->send(200, "text/html", paginaHTML());
  });

  server.on("/forward2000", HTTP_GET, [](AsyncWebServerRequest *request) {
    motorAdelante(PWM_ALTO);
    request->send(200, "text/html", paginaHTML());
  });

  server.on("/backward500", HTTP_GET, [](AsyncWebServerRequest *request) {
    motorAtras(PWM_BAJO);
    request->send(200, "text/html", paginaHTML());
  });

  server.on("/backward2000", HTTP_GET, [](AsyncWebServerRequest *request) {
    motorAtras(PWM_ALTO);
    request->send(200, "text/html", paginaHTML());
  });

  server.on("/stop", HTTP_GET, [](AsyncWebServerRequest *request) {
    motorDetener();
    request->send(200, "text/html", paginaHTML());
  });

  server.begin();
}

void loop() {
  unsigned long tActual = millis();

  if (tActual - tAnterior >= periodo) {
    long ticksActuales;

    noInterrupts();
    ticksActuales = ticksEncoder1;
    interrupts();

    long deltaTicks = ticksActuales - ticksPrevios;
    float dt = (tActual - tAnterior) / 1000.0;

    ticksPrevios = ticksActuales;
    tAnterior = tActual;

    float vueltas = deltaTicks / 12.0;   // 12 pulsos = 1 vuelta
    omega = (vueltas * 2.0 * PI) / dt;
    rpm = (vueltas / dt) * 60.0;

    Serial.print("Estado: ");
    Serial.print(estadoMotor);
    Serial.print(" | PWM: ");
    Serial.print(pwmActual);
    Serial.print(" | Omega(rad/s): ");
    Serial.print(omega);
    Serial.print(" | RPM: ");
    Serial.print(rpm);
    Serial.print(" | Ticks: ");
    Serial.println(ticksActuales);
  }

  // =========================
  // Control por ticks
  // =========================
  // Esto estaba antes, lo dejo por si acaso
  //if (ticksEncoder1 >= 1800) {
  //  motorAtras(PWM_BAJO);
  //}
  //else if (ticksEncoder1 <= -1800) {
  //  motorAdelante(PWM_BAJO);
  //}
  //*/

  delay(20);
}

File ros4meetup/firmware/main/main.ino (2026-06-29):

#include <ArduinoJson.h>
#include <WiFi.h>
#include <esp_now.h>


// ==== Pines para los motores (Drivers 8871) ====
#define SDA 15
#define SCL 16

// ==== Pines motores y encoders (definidos abajo para inicializar objetos) ====
#define M1_IN1 1
#define M1_IN2 2
#define ENC1_A 4
#define ENC1_B 5
#define M2_IN1 6
#define M2_IN2 7
#define ENC2_A 17
#define ENC2_B 18
#define M3_IN1 8
#define M3_IN2 3
#define ENC3_A 9
#define ENC3_B 10
#define M4_IN1 11
#define M4_IN2 13
#define ENC4_A 13
#define ENC4_B 14

String input;
uint8_t senderAddress[] = {0x0c, 0x4e, 0xa0, 0x65, 0xaf, 0x30}; // ejemplo
int data[4] = {0, 0, 0, 0};

// ------------------------------------------------------------------

// ==== Callback ESP-NOW: firma compatible con esp_now_recv_cb_t ====
void OnDataRecv(const esp_now_recv_info_t *info, const uint8_t *incomingData, int len)
{
    // info puede ser nullptr en algunas implementaciones; comprobarlo
    if (incomingData == nullptr || len <= 0)
        return;

    StaticJsonDocument<200> doc;
    DeserializationError error = deserializeJson(doc, incomingData, len);
    if (!error)
    {
        updateData(doc);
    }
    else
    {
        // opcional: imprimir error para debugging
        Serial.print("ESP-NOW Deserialize error: ");
        Serial.println(error.c_str());
    }
}


// ==== Clase Motor con encoder ====
class Motor
{
private:
    int in1, in2;
    int encA, encB;
    volatile long pulsos;
    long lastPulsos;
    float rpm;
    unsigned long lastTime;
    const int pulsosPorVuelta = 12;
    const float reduccion = 80.0;

public:
    Motor(int _in1, int _in2, int _ch1, int _ch2, int _encA, int _encB)
    {
        in1 = _in1;
        in2 = _in2;
        encA = _encA;
        encB = _encB;
        pulsos = 0;
        lastPulsos = 0;
        rpm = 0;
        lastTime = millis();
    }

    void init()
    {
        pinMode(in1, OUTPUT);
        pinMode(in2, OUTPUT);

        // No ledcSetup, just prepare pins for analogWrite
        analogWrite(in1, 0);
        analogWrite(in2, 0);

        pinMode(encA, INPUT_PULLUP);
        pinMode(encB, INPUT_PULLUP);
        attachInterruptArg(digitalPinToInterrupt(encA), isrA, this, CHANGE);
        attachInterruptArg(digitalPinToInterrupt(encB), isrB, this, CHANGE);
    }

    void forward(int speed)
    {
        speed = (constrain(speed, 0, 100) / 100) * 255;
        analogWrite(in1, speed);
        analogWrite(in2, 0);
    }

    void backward(int speed)
    {
        speed = (constrain(speed, 0, 100) / 100) * 255;
        analogWrite(in1, 0);
        analogWrite(in2, speed);
    }

    void stop()
    {
        analogWrite(in1, 0);
        analogWrite(in2, 0);
    }

    void updateRPM()
    {
        unsigned long now = millis();
        if (now - lastTime >= 500)
        {
            long delta = pulsos - lastPulsos;
            float tiempoSeg = (now - lastTime) / 1000.0;
            rpm = (delta / (float)pulsosPorVuelta) * (60.0 / tiempoSeg) / reduccion;
            lastPulsos = pulsos;
            lastTime = now;
        }
    }

    float getRPM() { return rpm; }
    long getPulsos() { return pulsos; }

    void encoderChange(bool a, bool b)
    {
        if (a == b)
            pulsos++;
        else
            pulsos--;
    }

    static void isrA(void *arg)
    {
        Motor *m = static_cast<Motor *>(arg);
        m->encoderChange(digitalRead(m->encA), digitalRead(m->encB));
    }

    static void isrB(void *arg)
    {
        Motor *m = static_cast<Motor *>(arg);
        m->encoderChange(digitalRead(m->encA), digitalRead(m->encB));
    }
};

// ==== Instancias ====
Motor motor1(M1_IN1, M1_IN2, 0, 1, ENC1_A, ENC1_B);
Motor motor2(M2_IN1, M2_IN2, 2, 3, ENC2_A, ENC2_B);
Motor motor3(M3_IN1, M3_IN2, 4, 5, ENC3_A, ENC3_B);
Motor motor4(M4_IN1, M4_IN2, 6, 7, ENC4_A, ENC4_B);

// ==== Movimiento simple ====
void moveForward(int v)
{
    motor1.forward(v);
    motor2.forward(v);
    motor3.forward(v);
    motor4.forward(v);
}
void move(int v1, int v2, int v3, int v4)
{
    (v1 >= 0) ? motor1.forward(v1) : motor1.backward(-v1);
    (v2 >= 0) ? motor2.forward(v2) : motor2.backward(-v2);
    (v3 >= 0) ? motor3.forward(v3) : motor3.backward(-v3);
    (v4 >= 0) ? motor4.forward(v4) : motor4.backward(-v4);
}
void stopAll()
{
    motor1.stop();
    motor2.stop();
    motor3.stop();
    motor4.stop();
}
void handleStatus()
{
    motor1.updateRPM();
    motor2.updateRPM();
    motor3.updateRPM();
    motor4.updateRPM();

    StaticJsonDocument<200> doc;
    doc["rpm1"] = motor1.getRPM();
    doc["rpm2"] = motor2.getRPM();
    doc["rpm3"] = motor3.getRPM();
    doc["rpm4"] = motor4.getRPM();
    doc["pulsos1"] = motor1.getPulsos();
    doc["pulsos2"] = motor2.getPulsos();
    doc["pulsos3"] = motor3.getPulsos();
    doc["pulsos4"] = motor4.getPulsos();

    String response;
    serializeJson(doc, response);
}

void sendData()
{
    motor1.updateRPM();
    motor2.updateRPM();
    motor3.updateRPM();
    motor4.updateRPM();

    StaticJsonDocument<200> doc;
    doc["rpm1"] = motor1.getRPM();
    doc["rpm2"] = motor2.getRPM();
    doc["rpm3"] = motor3.getRPM();
    doc["rpm4"] = motor4.getRPM();
    doc["pulsos1"] = motor1.getPulsos();
    doc["pulsos2"] = motor2.getPulsos();
    doc["pulsos3"] = motor3.getPulsos();
    doc["pulsos4"] = motor4.getPulsos();

    char output[200];
    serializeJson(doc, output);
    Serial.println(output);
    // Si quieres enviar a una dirección concreta:
    esp_err_t res = esp_now_send(senderAddress, (uint8_t *)output, strlen(output));
    if (res != ESP_OK)
    {
        Serial.print("esp_now_send error: ");
        Serial.println(res);
    }
}

// ==== Setup ====
void setup()
{
    Serial.begin(115200);



    Serial.println(WiFi.localIP());


    // Initialize ESP-NOW
    WiFi.mode(WIFI_STA);
    delay(100);

    if (esp_now_init() != ESP_OK)
    {
        Serial.println("Error initializing ESP-NOW");
    }
    else
    {
        Serial.println("ESP-NOW initialized.");
    }

    // Registrar callback (firma compatible)
    esp_err_t r = esp_now_register_recv_cb(OnDataRecv);
    if (r != ESP_OK)
    {
        Serial.print("esp_now_register_recv_cb error: ");
        Serial.println(r);
    }

    // Añadir peer (si lo necesitas)
    esp_now_peer_info_t peerInfo = {};
    memcpy(peerInfo.peer_addr, senderAddress, 6);
    peerInfo.channel = 0;
    peerInfo.encrypt = false;
    if (esp_now_add_peer(&peerInfo) != ESP_OK)
    {
        Serial.println("Failed to add peer");
    }

    motor1.init();
    motor2.init();
    motor3.init();
    motor4.init();

    Serial.println("Motores con encoder inicializados.");
}
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
